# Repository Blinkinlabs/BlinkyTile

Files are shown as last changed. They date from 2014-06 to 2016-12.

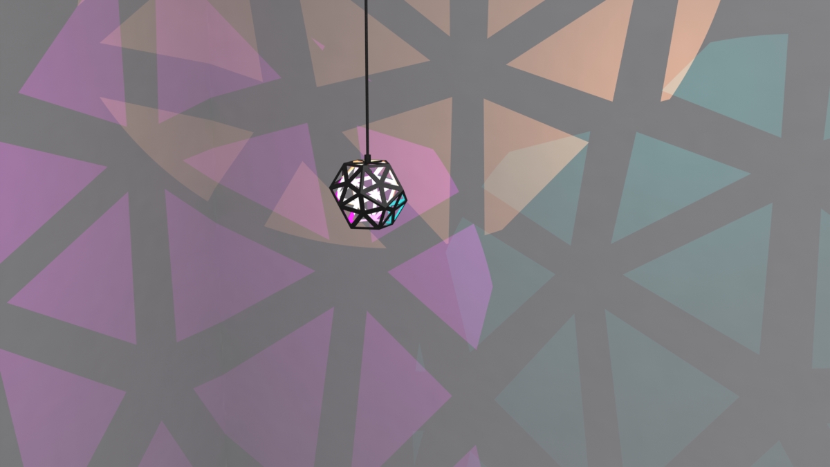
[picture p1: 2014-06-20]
concept_renderings/lamp concept.JPG

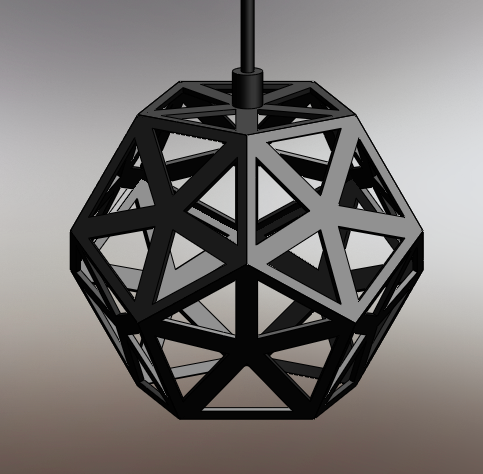
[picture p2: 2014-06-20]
concept_renderings/lamp base.jpg

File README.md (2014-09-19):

BlinkyTile: Build Your Own Dynamic Light Sculptures
==========



BlinkyTile is a very special type of pentagonal tile, designed to let you create your own custom light sculptures.

This is the source repository for the BlinkyTile design and software. For more information, head to:

http://blinkytile.com/

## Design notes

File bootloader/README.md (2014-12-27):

Modified Fadecandy Bootloader
=====

This is a simple open source bootloader for the Freescale Kinetis MK20DX128 microcontroller. It uses the USB Device Firmware Upgrade (DFU) standard. This bootloader was developed for use with Fadecandy, but it should be portable with to other projects using chips in the Kinetis microcontroller family, including the MK20DN64.

Installing
---

On a Teensy 3.0, you can use the Teensy Loader application to install `fc-boot.hex`. Afterwards, your Teensy should appear to the system as a "Fadecandy Bootloader" USB device capable of loading an application firmware image.

On a Fadecandy fc64x8 board, the bootloader can be installed via JTAG using OpenOCD. If you have an Olimex ARM-USB-OCD adapter, everything's already set up to install the bootloader with "make install". Other JTAG adapters will require changing `openocd.cfg`. Note: This may need to be modified to work with the LightBuddy microcontroller, specifically any sections referring to FlexRam.

Application Interface
---

This section describes the programming interface that exists between the bootloader and the application firmware.

The bootloader uses the smallest possible protected region on the MK20DX128's flash, a 4KB block. It uses a tiny amount of RAM for a "token" which is used to force entry into the bootloader on system reset.

When entering the application firmware, the system clocks will already be configured, and the watchdog timer is already enabled with a 10ms timeout. The application may disable the watchdog timer if desired.

The bootloader normally transfers control to the application early in boot, before setting up the USB controller. It will skip this step and run the DFU implementation if any of the following conditions are true:

* Both user buttons are pressed during power on (Manual recovery)
* A 32-bit entry token (0x74624346, or 'FCbt') is found at 0x2000_1FFC. (Programmatic entry)
* The application ResetVector does not reside within application flash. (No application is installed)

Memory address range       | Description
-------------------------- | ----------------------------
0x0000_0000 - 0x0000_0FFF  | Bootloader protected flash
0x0000_1000 - 0x0000_10F7  | Application IVT in flash
0x0000_1000 - 0x0001_FFFF  | Remainder of application flash
0x1FFF_E000 - 0x2000_1FFC  | Application SRAM
0x2000_1FFC - 0x2000_1FFF  | Entry token in SRAM

External Hardware
---

No external hardware is required for the bootloader to operate. The following pins are used by the bootloader for optional features:

* PD6 is a status LED, active (low) while the bootloader is in DFU mode.

File Format
---

The DFU file consists of raw 1 kilobyte blocks to be programmed into flash starting at address 0x0000_1000. The file may contain up to 63 blocks. No additional headers or checksums are included. On disk, the standard DFU suffix and CRC are used. During transit, the standard USB CRC is used.

Contact
---

Matt Mets <<matt@blinkinlabs.com>>

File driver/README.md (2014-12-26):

= Build a DFU driver for the BlinkyTile bootloader

Start with instructions here:
https://github.com/libusbx/libusbx/wiki/Windows-Backend#Driver_Installation

use this set for reference:
http://libusb-winusb-wip.googlecode.com/files/winusb%20driver.zip

Modify the 'libusb_device_multiple_interfaces_0' example to include the Light Buddy runtime interface.
Modify the 'libusb_device' example to include the Light Buddy interface

= Updating firmware on Windows

Get dfu-util 0.8 from the web site:
http://dfu-util.sourceforge.net/releases/dfu-util-0.8-binaries/win32-mingw32/

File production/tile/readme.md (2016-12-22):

The tile test jig is designed to run on a Teensy 3.0 or 3.1

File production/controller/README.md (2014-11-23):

Fadecandy Test Jig
==================

This is a simple one-off test fixture that's designed to facilitate in-circuit debugging of the Fadecandy firmware, and doing reliable low-volume production.

My prototype consists of:

* An ugly hand-wired perfboard
* 0.1"-spaced pogo pins which connect to the Fadecandy board's "hacker port" as well as its output header
* A standard ARM JTAG header for firmware development using an external JTAG adapter
* A 2-LED string of WS2811 LEDs, for verifying the timing of the Fadecandy outputs
* A Teensy 3.0 board which coordinates production and testing tasks

The board is intended for two separate use cases:

* During firmware development, it's a simple breakout board for the JTAG port
* During low-volume production, the Teensy installs firmware and performs electrical testing

This board is a work-in-progress. This directory contains Teensyduino sketches which run on the onboard Teensy. More information about the hardware will be included later.

Hardware tidbits
----------------

* JTAG port uses 10K pull-up resistors to target's' 3.3v rail on all signals.
* Pogo pins are 2x Digi-Key part ED8178-16-ND
* Big green button next to pogo-pins to initiate programming/test

Teensy 3.0 pin assignment
-------------------------

Pin      | Description
-------- | ----------------------------------
Gnd      | Shared ground
Vin      | +5V power for testjig itself
0        | Teensy RX, target TX
1        | Teensy TX, target RX
2        | To ground via green button
3        | target TCLK (SWCLK)
4        | target TMS (SWDIO)
5        | target USB D- (white wire)
6        | target USB D+ (green wire)
7        | target USB shield ground
8        | target USB signal ground
9        | (No connection)
10       | PWM out for power supply control
11       | PASS LED (to ground)
12       | FAIL LED (to ground)
13       | (Teensy built-in LED)
14 (A0)  | target output 0 (via resistor divider) PA4
15 (A1)  | target output 1 (via resistor divider) PB0
16 (A2)  | target output 2 (via resistor divider) PC1
17 (A3)  | target output 3 (via resistor divider)
18 (A4)  | target output 4 (via resistor divider)
19 (A5)  | target output 5 (via resistor divider)
20 (A6)  | target output 6 (via resistor divider) PB1
21 (A7)  | target output 7 (via resistor divider)
22 (A8)  | target 3.3v     (via resistor divider)
23 (A9)  | target VUSB     (via resistor divider)

All analog inputs connect via the same resistor divider:

* 1K between analog input and ground
* 6.8K between analog input and Fadecandy signal
* Use 5% tolerance resistors or better

Target power supply (micro-USB cable) is driven at a variable voltage. This is achieved by buffering a PWM output with an RC filter and op-amp.

* Op-amp should be able to drive ~20mA. I used half an OPA2350, since it was handy.
* Op-amp supply voltage driven by Teensy VUSB (~5V), bypassed with 0.1uF cap
* Configured as a non-inverting amplifier with gain=2
  * Feedback resistor, - to out, 68K
  * Feedback resistor, - to ground, 68K
* Low-pass filter on + input
  * 68K between + and PWM input
  * 0.1uF capacitor between + and ground
* Unused op-amps configured as followers
  * 33K from - to out
  * 33K from + to ground

The Teensy isn't capable of communicating over USB with the Fadecandy board when wired this way, but the USB pins are electrically tested in a minimal way. Note that the USB signal ground and shield ground are set up this way only for electrical testing. During testing and programming, the actual power and signal ground is achieved through the test clip's connection to the output port. Except for VUSB, all signals on the USB connector are used only to electrically test the USB connector itself.

Testjig Firmwares
-----------------

* `production`
	* Programs bootloader and initial firmware image
	* Runs electrical tests
	* Communicates with the DUT processor using Serial Wire Debug
* `serial_passthrough`
	* Teensyduino sketch
    * Appears as a USB serial port device
	* Passes through access to the DUT serial port
	* When the green button is held, acts as a loopback for the DUT serial port, as one way to enter FC-Boot.

Contact
-------

Micah Elizabeth Scott <<micah@scanlime.org>>

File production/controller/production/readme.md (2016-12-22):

Note:

For debug messages to work correctly, the Teensyduino build file needs to be modified. In:

	/c/Program Files (x86)/Arduino/hardware/teensy/avr/boards.txt

Change the line:

	teensy30.build.flags.ld=-Wl,--gc-sections,--relax,--defsym=__rtc_localtime={extra.time.local} "-T{build.core.path}/mk20dx128.ld"

to:

	teensy30.build.flags.ld=-Wl,-u_printf_float,--gc-sections,--relax,--defsym=__rtc_localtime={extra.time.local} "-T{build.core.path}/mk20dx128.ld"

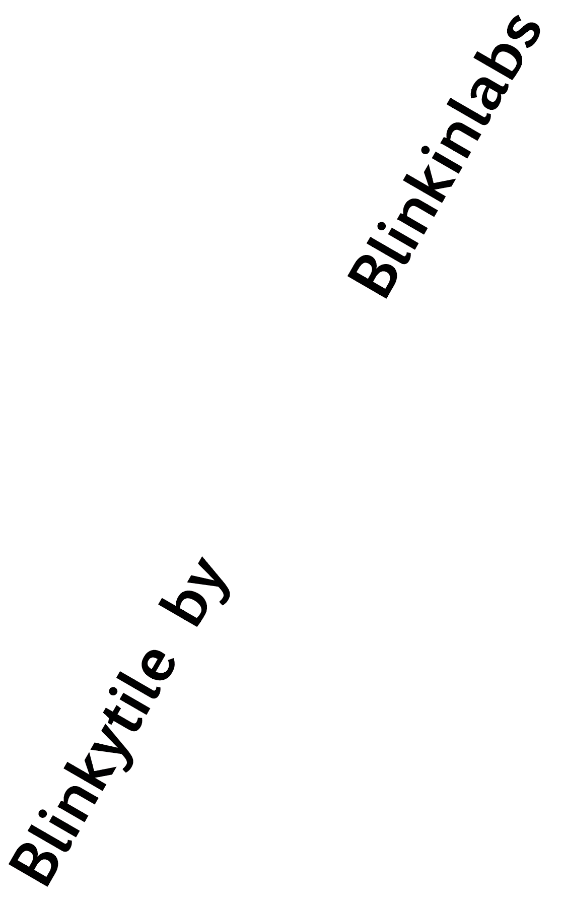
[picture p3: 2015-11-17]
tile_pcb/BlinkyTile Hexagon art.bmp

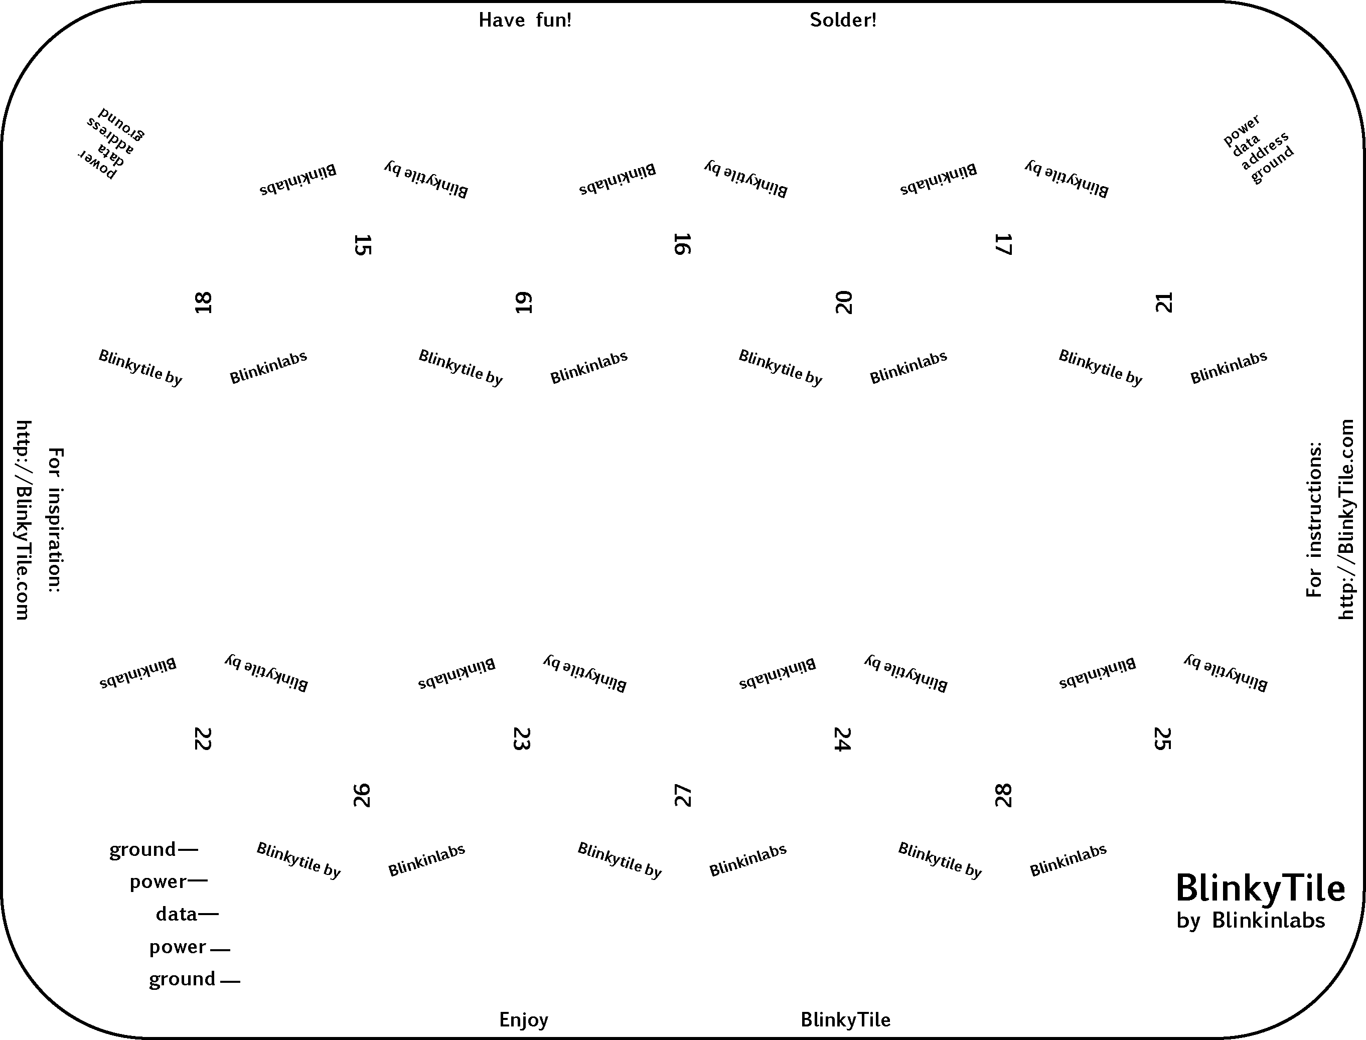
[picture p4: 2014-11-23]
tile_pcb/BlinkyTile_panel_15_28.BMP

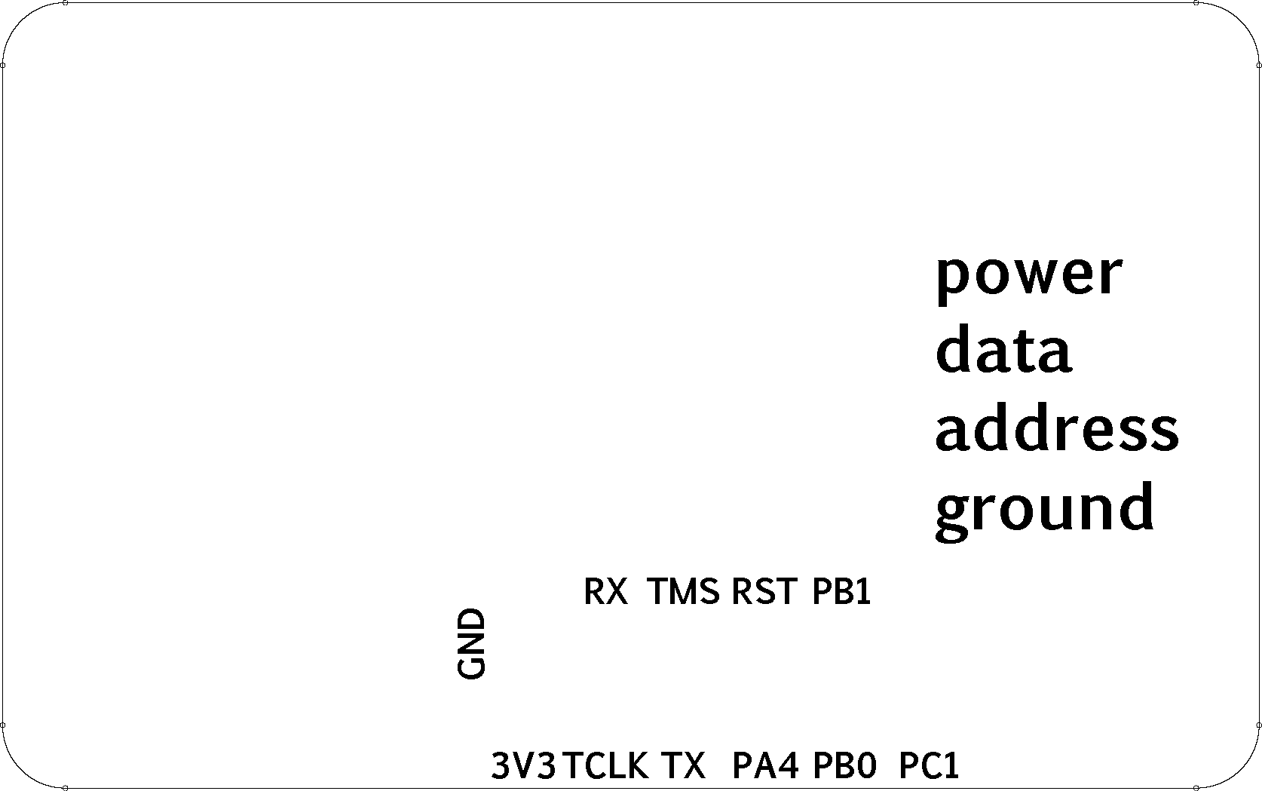
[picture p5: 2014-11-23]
controller_pcb/BlinkyTile Controller_Top.BMP

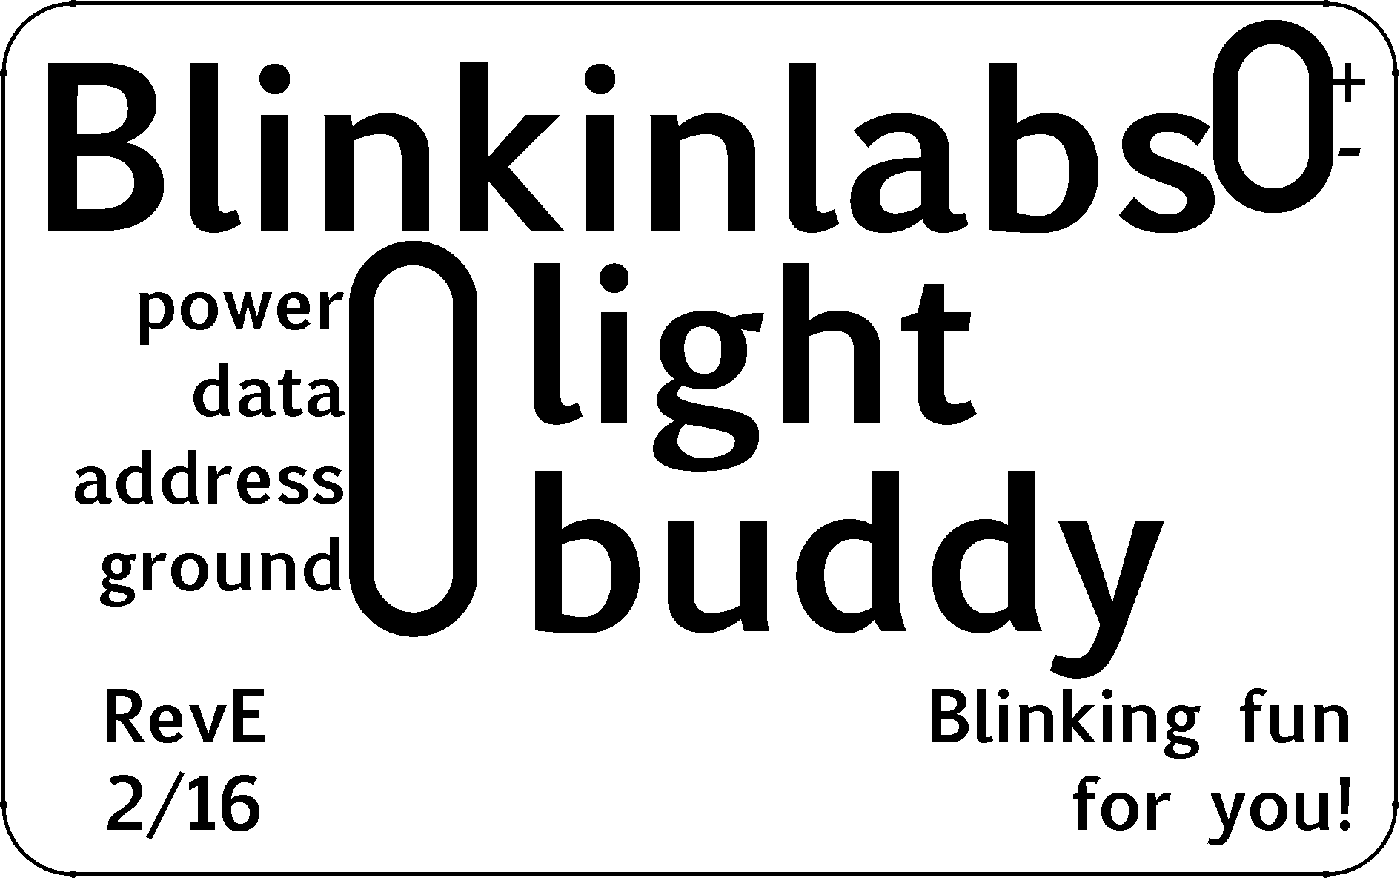
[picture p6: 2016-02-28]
controller_pcb/BlinkyTile Controller_Bottom.BMP

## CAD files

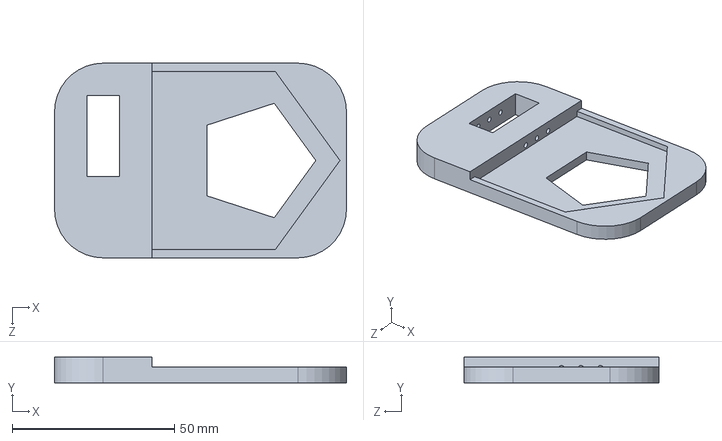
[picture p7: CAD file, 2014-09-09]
tile_programming_jig/programmer base.SLDPRT
90.0 x 8.00 x 60.0 mm

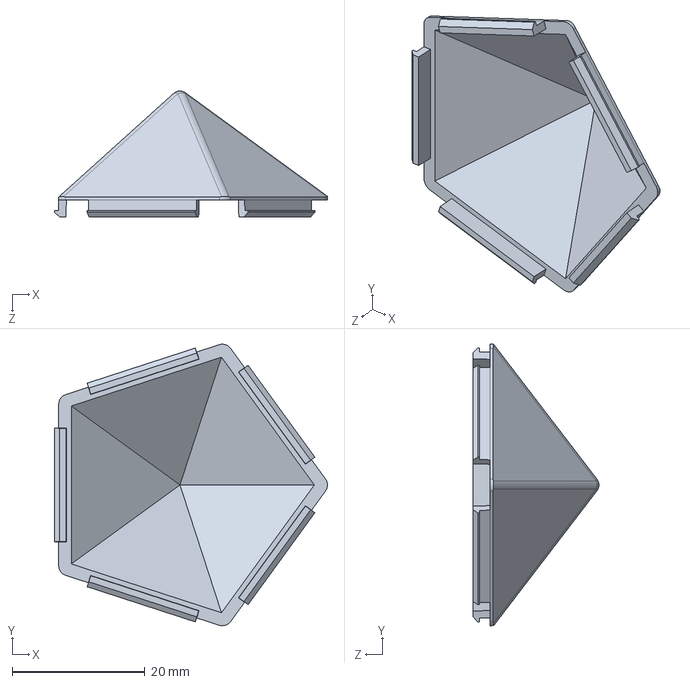
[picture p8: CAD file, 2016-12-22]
toppers/pyramid_nostep-revB-1.6mm-1.2clip.SLDPRT
41.2 x 42.5 x 19.0 mm

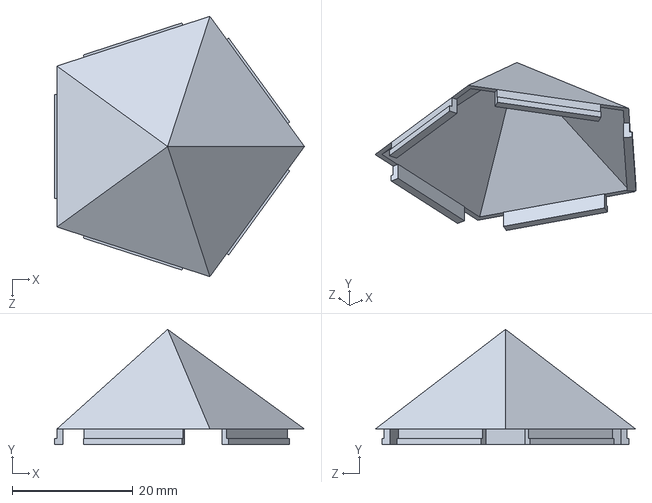
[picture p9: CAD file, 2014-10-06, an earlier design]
toppers/pyramid_nostep.SLDPRT
41.4 x 19.1 x 43.1 mm

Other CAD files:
toppers/pyramid_nostep-revB-1.5mm.STL
toppers/pyramid_nostep-revB.SLDPRT
tile_programming_jig/programmer base.STL
toppers/pyramid_nostep-revB-1.6mm-1.2clip.STL
toppers/pyramid_nostep-revB.STL
toppers/pyramid_nostep.STL

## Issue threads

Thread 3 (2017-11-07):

Blinky Tile firmware on Fade Candy

dunk8888, 2017-11-07:
Hi i was wondering if i could load blinky tile firmware on my fadecandy and use it with pattern paint?

dunk8888, 2017-11-07:
Also does the blinky tile run ws2812b leds too?

cibomahto, 2017-11-08:
Unfortunately, it's not compatible with the FadeCandy board- it's using a different processor and circuit. You'd need to re-write the firmware and add a flash chip to the FadeCandy board to make it work.

The supported firmware only supports BlinkyTile-style LEDs (DMX signalling with TTL line levels). There's an unsupported 'polyglot' branch that can output WS2812 control signals, but it is unstable.

The 'controller_pcb_tiny/' branch was a prototype of a smaller controller, but is also unfortunately not supported. If you're new to microcontroller development, I'd recommend using a different platform since this one is pretty hacky. In particular, I'd recommend looking at the ESP8266, and take a look at our EightByEight badge- we have support for that in PatternPaint, and the code could fairly easily be modified to output WS2812b outputs.

Closed 2017-11-08.

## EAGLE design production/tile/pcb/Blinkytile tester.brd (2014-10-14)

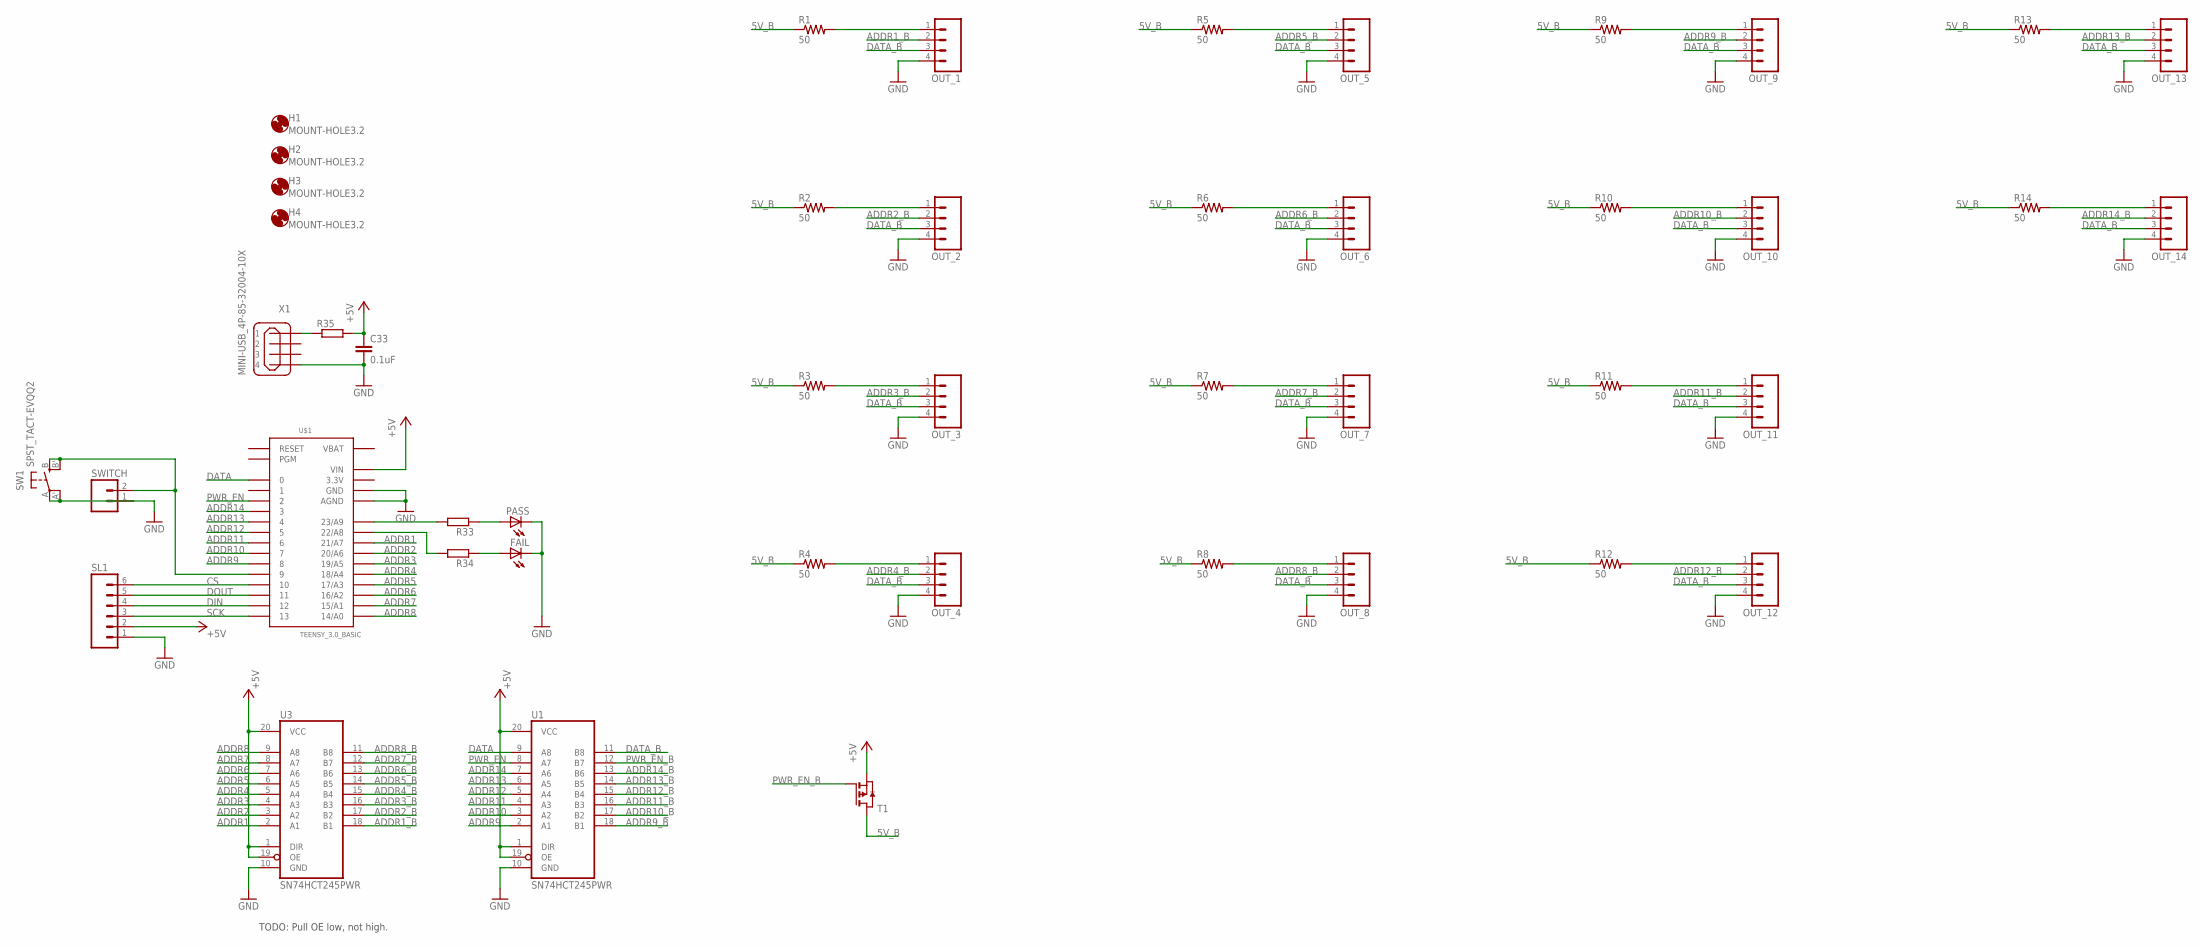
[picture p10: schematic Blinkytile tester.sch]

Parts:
C33: 0.1uF; C0805
FAIL: LED5MM
H1, H2, H3, H4: MOUNT-HOLE3.2; 3,2
OUT_1, OUT_2, OUT_3, OUT_4, OUT_5, OUT_6, OUT_7, OUT_8, OUT_9, OUT_10, OUT_11, OUT_12, OUT_13, OUT_14: M04; 04P
PASS: LED5MM
R1, R2, R3, R4, R5, R6, R7, R8, R9, R10, R11, R12, R13, R14: 50; R0603
R33, R34, R35: R-EU_M0805; M0805
SL1: M06; 06P
SW1: SPST_TACT-EVQQ2; EVQ-Q2
SWITCH: M02; 02P
T1: PMOSSOT223; SOT223
U1, U3: SN74HCT245PWR; TSSOP20
U$1: TEENSY_3.0_BASIC
X1: MINI-USB_4P-85-32004-10X; 85-32004-10X

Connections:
3.3V: U$1.3.3V, U$1.3.3V1 (3.3V)
5V_B: R1.1, R2.1, R3.1, R4.1, R5.1, R6.1, R7.1, R8.1, R9.1, R10.1, R11.1, R12.1, R13.1, R14.1, T1.2 (D), T1.4 (D)
+5V: C33.1, R35.2, SL1.2, T1.3 (S), U1.1 (DIR), U1.19 (OE), U1.20 (VCC), U3.1 (DIR), U3.19 (OE), U3.20 (VCC), U$1.VIN
ADDR1: U3.2 (A1), U$1.21/A7
ADDR1_B: OUT_1.2, U3.18 (B1)
ADDR2: U3.3 (A2), U$1.20/A6
ADDR2_B: OUT_2.2, U3.17 (B2)
ADDR3: U3.4 (A3), U$1.19/A5
ADDR3_B: OUT_3.2, U3.16 (B3)
ADDR4: U3.5 (A4), U$1.18/A4
ADDR4_B: OUT_4.2, U3.15 (B4)
ADDR5: U3.6 (A5), U$1.17/A3
ADDR5_B: OUT_5.2, U3.14 (B5)
ADDR6: U3.7 (A6), U$1.16/A2
ADDR6_B: OUT_6.2, U3.13 (B6)
ADDR7: U3.8 (A7), U$1.15/A1
ADDR7_B: OUT_7.2, U3.12 (B7)
ADDR8: U3.9 (A8), U$1.14/A0
ADDR8_B: OUT_8.2, U3.11 (B8)
ADDR9: U1.2 (A1), U$1.8
ADDR9_B: OUT_9.2, U1.18 (B1)
ADDR10: U1.3 (A2), U$1.7
ADDR10_B: OUT_10.2, U1.17 (B2)
ADDR11: U1.4 (A3), U$1.6
ADDR11_B: OUT_11.2, U1.16 (B3)
ADDR12: U1.5 (A4), U$1.5
ADDR12_B: OUT_12.2, U1.15 (B4)
ADDR13: U1.6 (A5), U$1.4
ADDR13_B: OUT_13.2, U1.14 (B5)
ADDR14: U1.7 (A6), U$1.3
ADDR14_B: OUT_14.2, U1.13 (B6)
CS: SL1.6, U$1.10
DATA: U1.9 (A8), U$1.0
DATA_B: OUT_1.3, OUT_2.3, OUT_3.3, OUT_4.3, OUT_5.3, OUT_6.3, OUT_7.3, OUT_8.3, OUT_9.3, OUT_10.3, OUT_11.3, OUT_12.3, OUT_13.3, OUT_14.3, U1.11 (B8)
DIN: SL1.4, U$1.12
DOUT: SL1.5, U$1.11
GND: C33.2, FAIL.K (C), OUT_1.4, OUT_2.4, OUT_3.4, OUT_4.4, OUT_5.4, OUT_6.4, OUT_7.4, OUT_8.4, OUT_9.4, OUT_10.4, OUT_11.4, OUT_12.4, OUT_13.4, OUT_14.4, PASS.K (C), SL1.1, SW1.A, SW1.A' (P1), SWITCH.1, U1.10 (GND), U3.10 (GND), U$1.AGND, U$1.GND, U$1.GND1 (GND), X1.4
GOOD: PASS.A, R33.1
unnamed: OUT_5.1, R5.2
unnamed: OUT_1.1, R1.2
unnamed: SW1.B (S), SW1.B' (S1), SWITCH.2, U$1.9
unnamed: OUT_2.1, R2.2
unnamed: OUT_3.1, R3.2
unnamed: OUT_4.1, R4.2
unnamed: OUT_6.1, R6.2
unnamed: OUT_7.1, R7.2
unnamed: OUT_8.1, R8.2
unnamed: OUT_9.1, R9.2
unnamed: OUT_10.1, R10.2
unnamed: OUT_11.1, R11.2
unnamed: OUT_13.1, R13.2
unnamed: OUT_14.1, R14.2
unnamed: OUT_12.1, R12.2
unnamed: R33.2, U$1.23/A9
unnamed: R34.2, U$1.22/A8
unnamed: FAIL.A, R34.1
unnamed: R35.1, X1.1
PWR_EN: U1.8 (A7), U$1.2
PWR_EN_B: T1.1 (G), U1.12 (B7)
SCK: SL1.3, U$1.13
VBAT: U$1.VBAT

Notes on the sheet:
TODO: Pull OE low, not high.

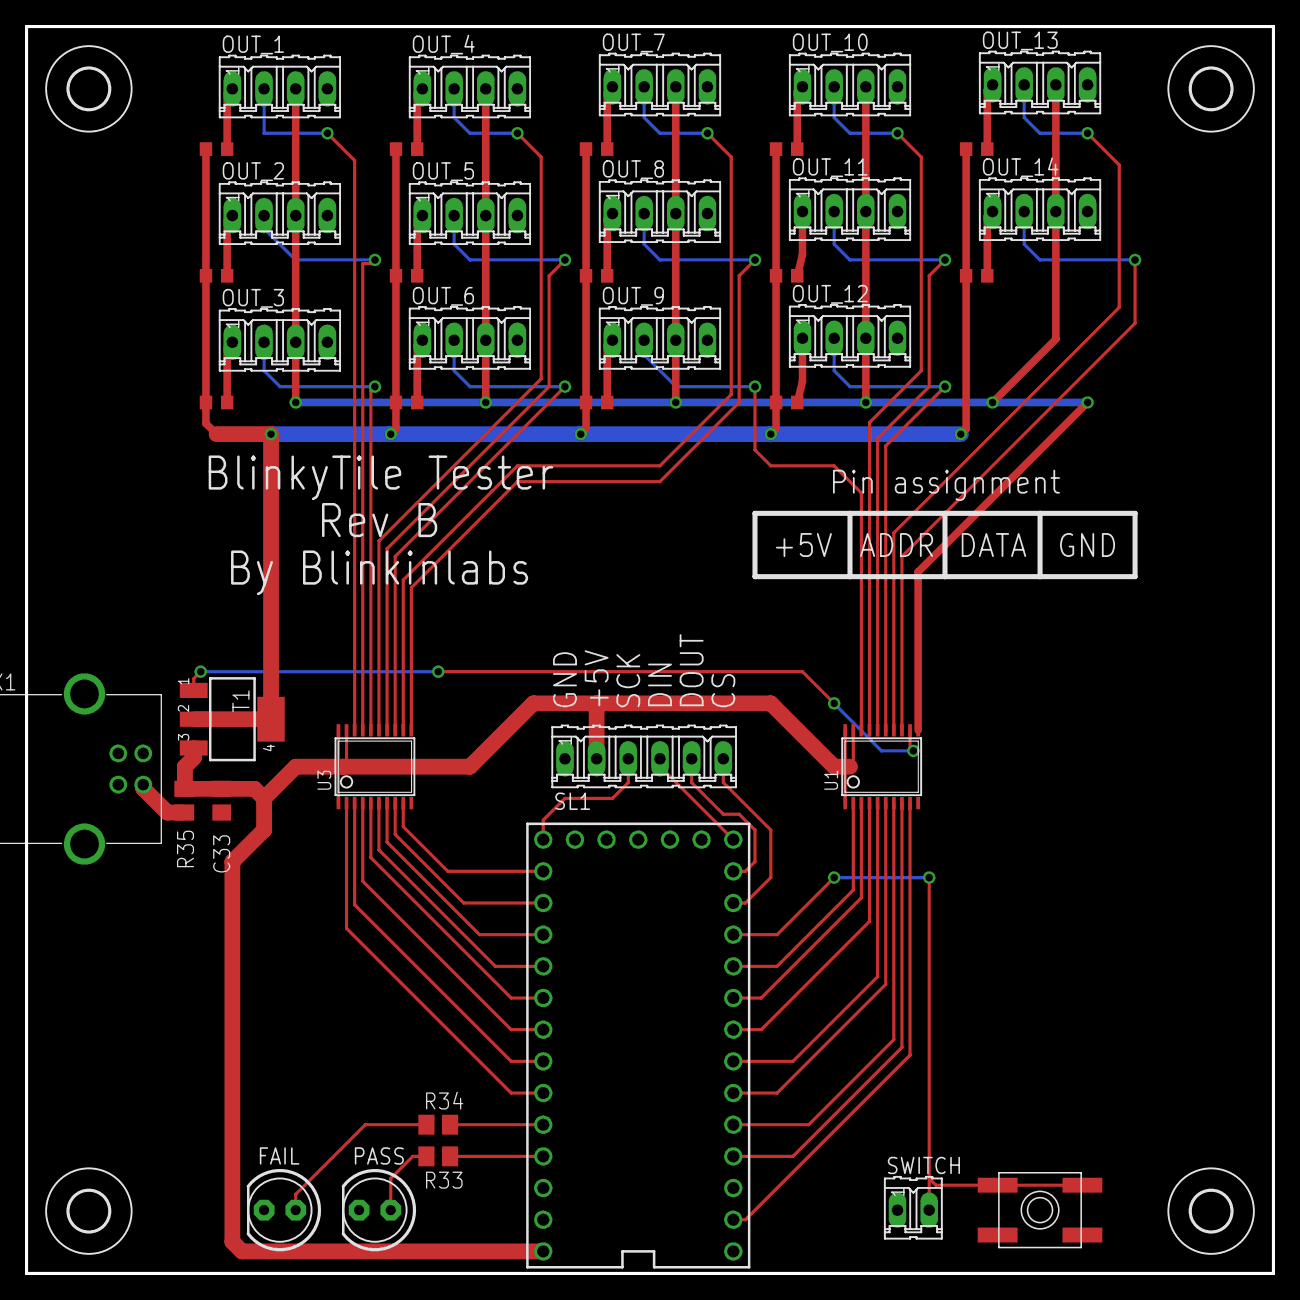
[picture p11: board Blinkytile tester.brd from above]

Board: 2 copper layers, 100.0 x 100.0 mm, 46 parts (0 on the bottom side), 60 nets.

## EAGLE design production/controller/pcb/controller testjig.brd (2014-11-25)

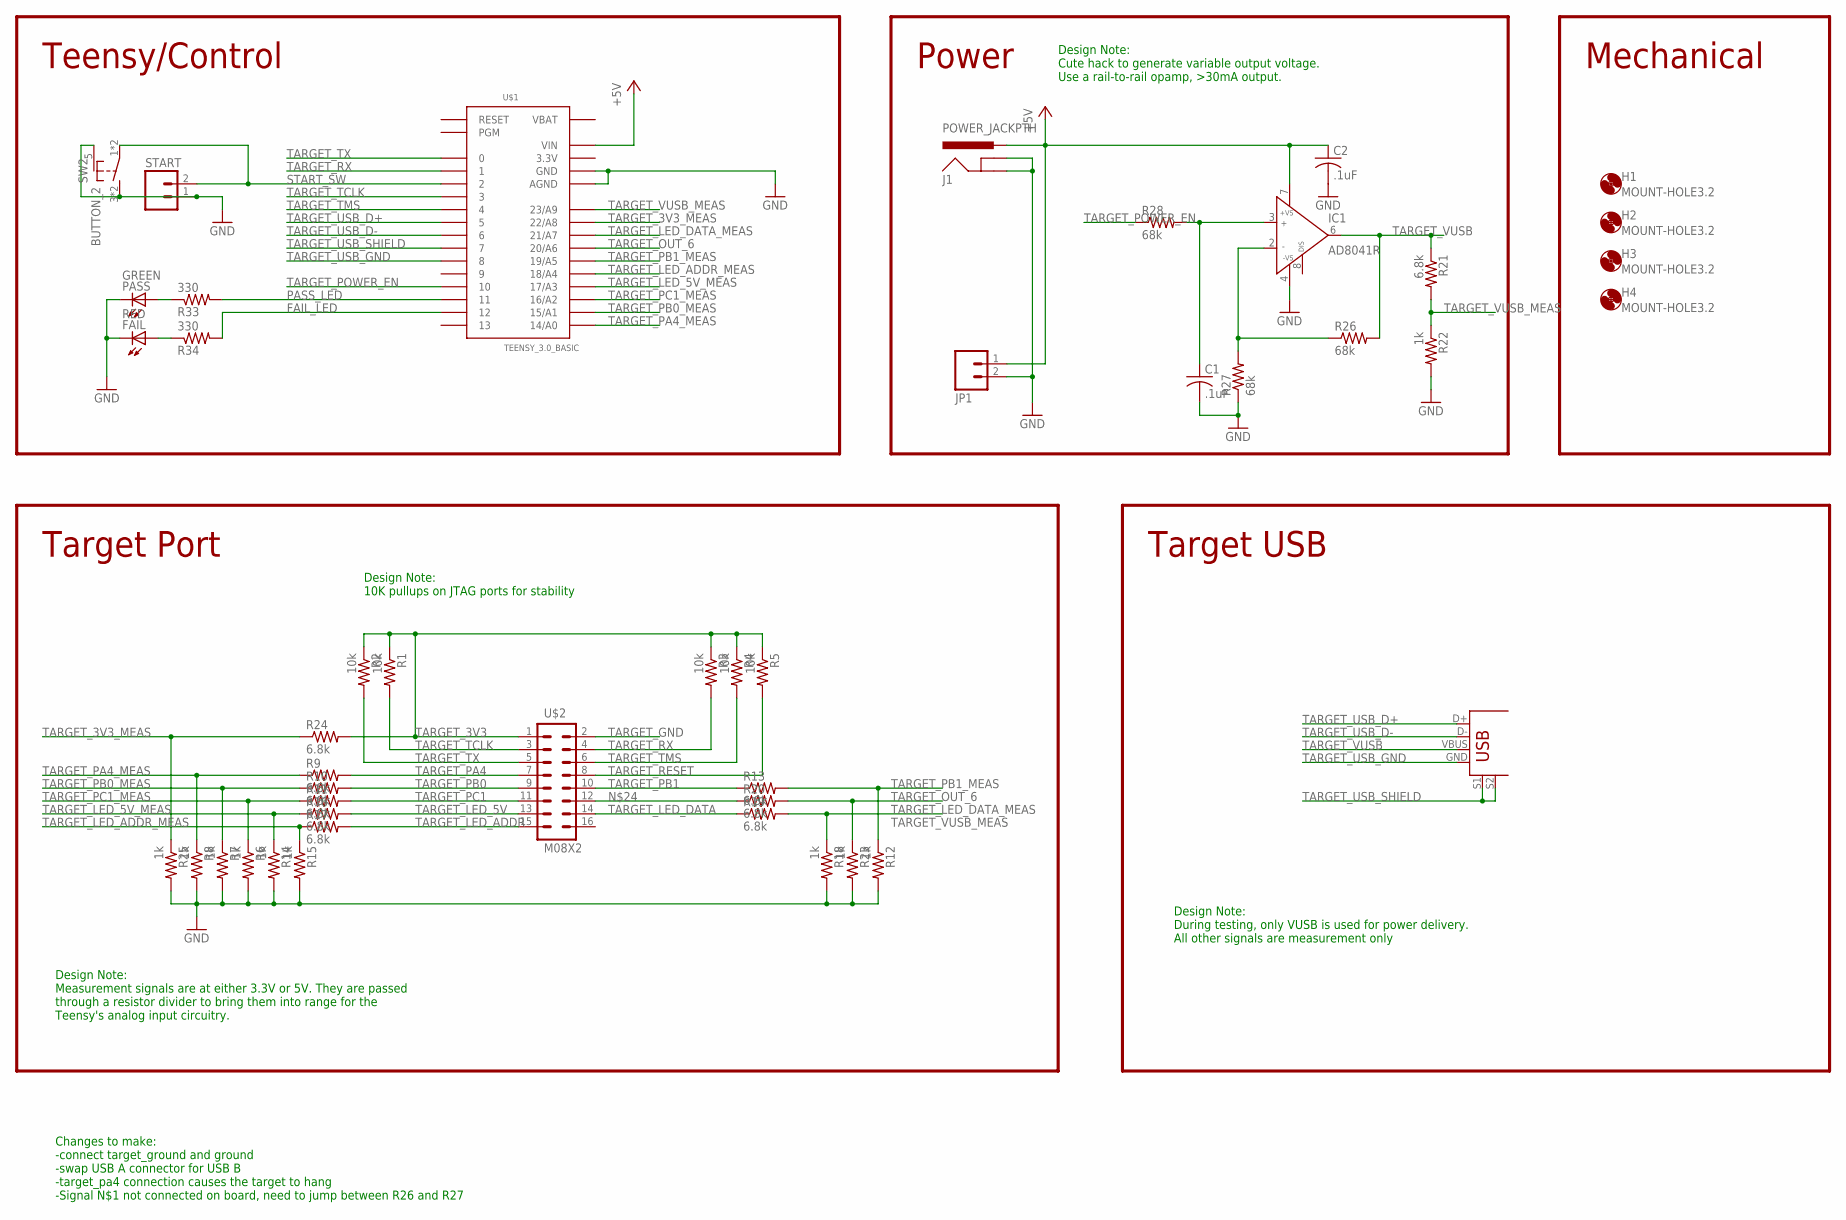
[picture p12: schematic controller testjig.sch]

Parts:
C1, C2: .1uF; C0603
FAIL: RED; LED5MM
H1, H2, H3, H4: MOUNT-HOLE3.2; 3,2
IC1: AD8041R; SO8
J1: POWER_JACKPTH; POWER_JACK_PTH
JP1: M023.5MM; SCREWTERMINAL-3.5MM-2
PASS: GREEN; LED5MM
R1, R2, R3, R4, R5: 10k; R0603
R6, R7, R8, R12, R14, R15, R18, R22, R23, R25: 1k; R0603
R9, R10, R11, R13, R16, R17, R19, R20, R21, R24: 6.8k; R0603
R26, R27, R28: 68k; R0603
R33, R34: 330; R0603
START: M02; 02P
SW2: BUTTON_2; TD-07XB
U$1: TEENSY_3.0_BASIC
U$2: M08X2; 2X8
U$3: USB+SHIELD; USB-B-PTH

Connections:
3.3V: U$1.3.3V, U$1.3.3V1 (3.3V)
+5V: C2.1, IC1.7 (+VS), J1.PWR, JP1.1, U$1.VIN
FAIL_LED: R34.2, U$1.12
GND: C1.2, C2.2, FAIL.K (C), IC1.4 (-VS), J1.GND, J1.GNDBREAK, JP1.2, PASS.K (C), R6.2, R7.2, R8.2, R12.2, R14.2, R15.2, R18.2, R22.2, R23.2, R25.2, R27.1, START.1, SW2.3 (S), SW2.4 (S), SW2.5 (SHIELD), U$1.AGND, U$1.GND, U$1.GND1 (GND)
GOOD: PASS.A, R33.1
unnamed: IC1.2 (IN-), R26.1, R27.2
unnamed: C1.1, IC1.3 (IN+), R28.2
unnamed: R20.1, U$2.12
unnamed: FAIL.A, R34.1
PASS_LED: R33.2, U$1.11
START_SW: START.2, SW2.1, SW2.2, U$1.2
TARGET_3V3: R1.1, R2.1, R3.1, R4.1, R5.1, R24.2, U$2.1
TARGET_3V3_MEAS: R24.1, R25.1, U$1.22/A8
TARGET_GND: U$2.2
TARGET_LED_5V: R16.2, U$2.13
TARGET_LED_5V_MEAS: R14.1, R16.1, U$1.17/A3
TARGET_LED_ADDR: R17.2, U$2.15
TARGET_LED_ADDR_MEAS: R15.1, R17.1, U$1.18/A4
TARGET_LED_DATA: R19.1, U$2.14
TARGET_LED_DATA_MEAS: R18.1, R19.2, U$1.21/A7
TARGET_OUT_6: R20.2, R23.1, U$1.20/A6
TARGET_PA4: R9.2, U$2.7
TARGET_PA4_MEAS: R8.1, R9.1, U$1.14/A0
TARGET_PB0: R10.2, U$2.9
TARGET_PB0_MEAS: R7.1, R10.1, U$1.15/A1
TARGET_PB1: R13.1, U$2.10
TARGET_PB1_MEAS: R12.1, R13.2, U$1.19/A5
TARGET_PC1: R11.2, U$2.11
TARGET_PC1_MEAS: R6.1, R11.1, U$1.16/A2
TARGET_POWER_EN: R28.1, U$1.10
TARGET_RESET: R5.2, U$2.8
TARGET_RX: R3.2, U$1.1, U$2.4
TARGET_TCLK: R1.2, U$1.3, U$2.3
TARGET_TMS: R4.2, U$1.4, U$2.6
TARGET_TX: R2.2, U$1.0, U$2.5
TARGET_USB_D+: U$1.5, U$3.D+
TARGET_USB_D-: U$1.6, U$3.D-
TARGET_USB_GND: U$1.8, U$3.GND
TARGET_USB_SHIELD: U$1.7, U$3.S1, U$3.S2
TARGET_VUSB: IC1.6 (OUT), R21.1, R26.2, U$3.VBUS
TARGET_VUSB_MEAS: R21.2, R22.1, U$1.23/A9
VBAT: U$1.VBAT

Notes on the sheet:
Teensy/Control
Target Port
Design Note: Measurement signals are at either 3.3V or 5V. They are passed through a resistor divider to bring them into range for the Teensy's analog input circuitry.
Design Note: 10K pullups on JTAG ports for stability
Mechanical
Target USB
Power
Design Note: During testing, only VUSB is used for power delivery. All other signals are measurement only
Design Note: Cute hack to generate variable output voltage. Use a rail-to-rail opamp, >30mA output.
Changes to make: -connect target_ground and ground -swap USB A connector for USB B -target_pa4 connection causes the target to hang -Signal N$1 not connected on board, need to jump between R26 and R27

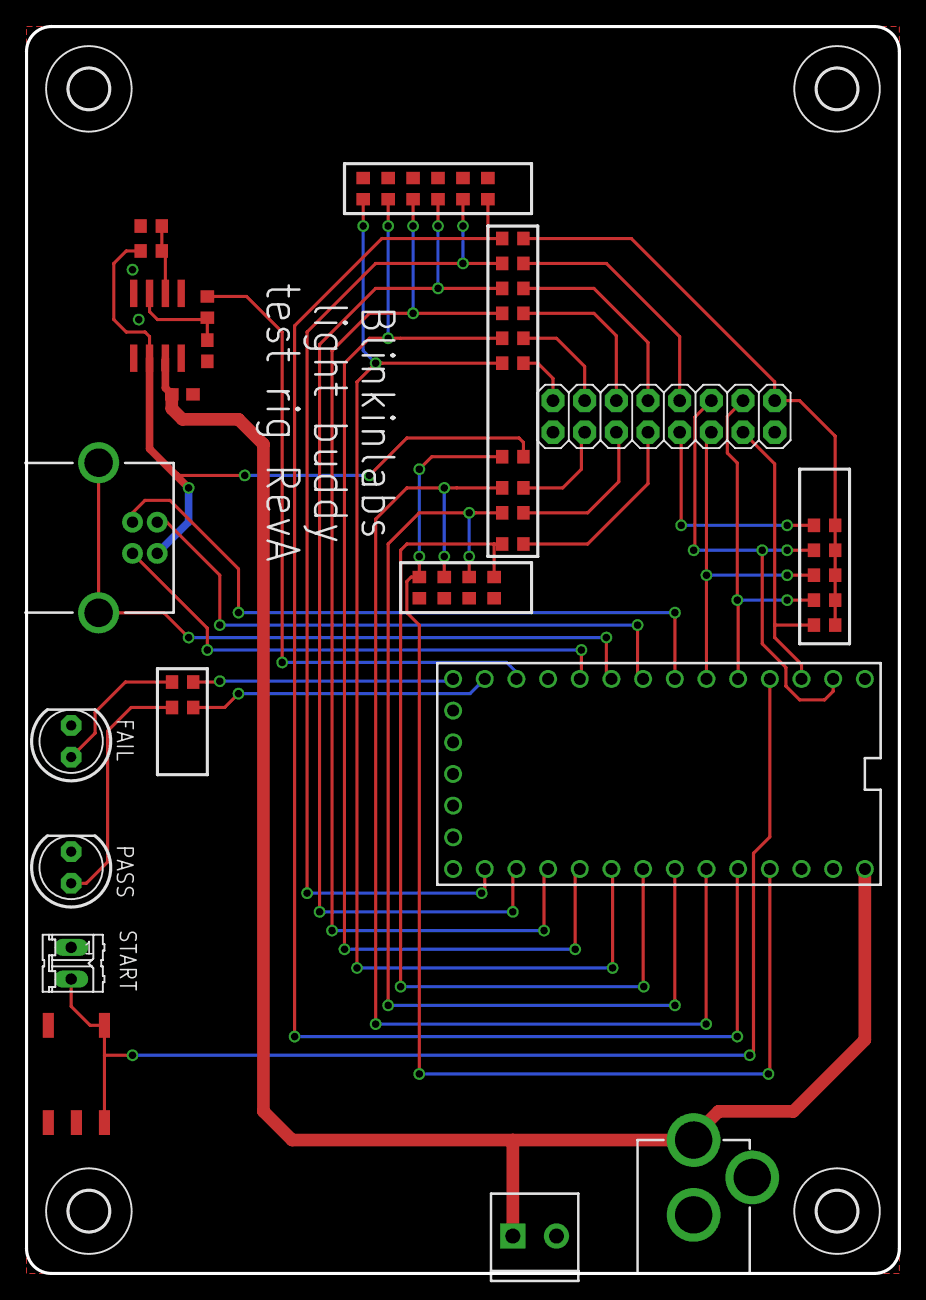
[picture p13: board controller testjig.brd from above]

Board: 2 copper layers, 70.0 x 100.0 mm, 46 parts (0 on the bottom side), 40 nets.

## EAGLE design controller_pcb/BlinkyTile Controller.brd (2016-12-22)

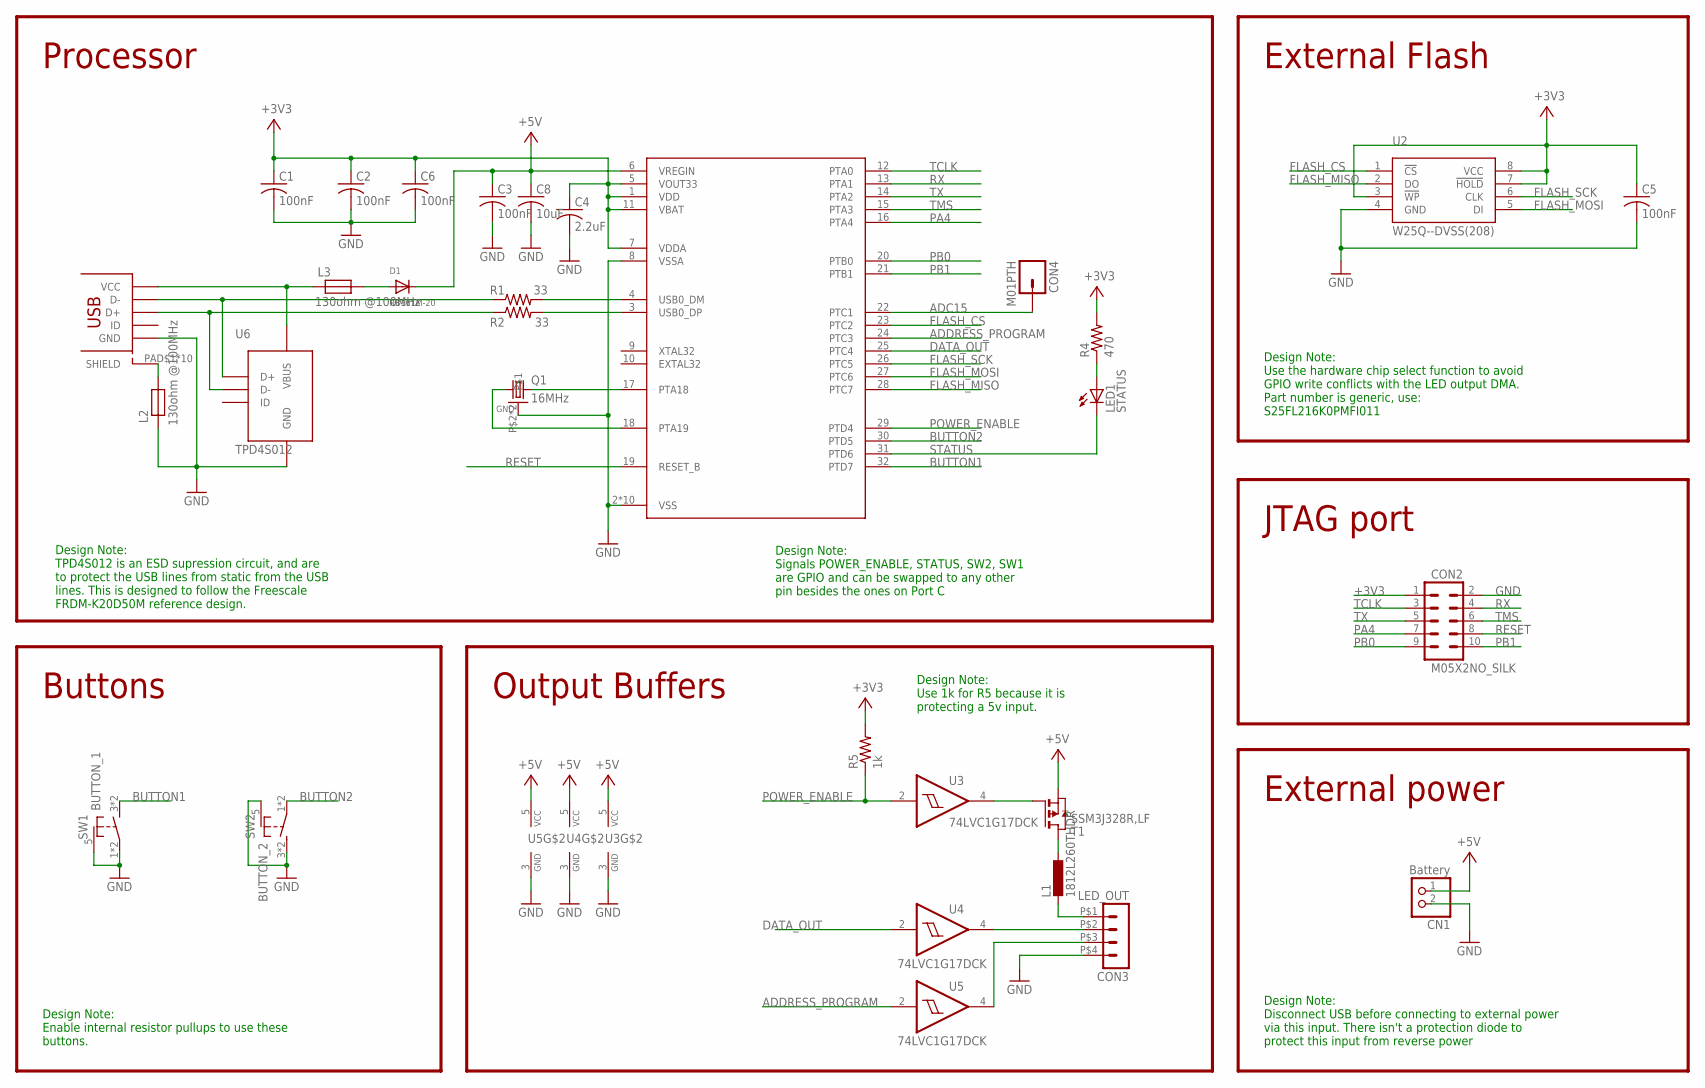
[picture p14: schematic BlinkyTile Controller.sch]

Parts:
C1, C2, C3, C5, C6: 100nF; C0402
C4: 2.2uF; C0402
C8: 10uF; C0805K
CN1: Battery; JST-PH-2-THM-RA
CON1: USB_MICROSMT+THRUHULE; USB_MICRO_THRUHOLE
CON2: M05X2NO_SILK; 2X5_NOSILK
CON3: LED_OUT; DUPONT-4P
CON4: M01PTH; 1X01
D1: RB161M-20; SOD-123
L1: 1812L260THDR; L1812
L2, L3: 130ohm @100MHz; 0805
LED1: STATUS; CHIPLED_0805
Q1: 16MHz; CRSYTAL_2520
R1, R2: 33; R0402
R4: 470; R0402
R5: 1k; R0402
SW1: BUTTON_1; TD-07XB
SW2: BUTTON_2; TD-07XB
T1: SSM3J328R,LF; SOT-23
U1: MK20D--VFM5; QFN32_5X5_LONGLEADS
U2: W25Q--DVSS(208); SOIC8-208
U3, U4, U5: 74LVC1G17DCK; SC70-5
U6: TPD4S012; R-PUSON-N6

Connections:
+3V3: C1.1, C2.1, C4.1, C5.1, C6.1, CON2.1, R4.2, R5.2, U1.1 (VDD), U1.5 (VOUT33), U1.7 (VDDA), U1.11 (VBAT), U2.3 (!WP), U2.7 (!HOLD), U2.8 (VCC)
+5V: C3.1, C8.1, CN1.1 (2), D1.C, T1.2 (S), U1.6 (VREGIN), U3.5 (VCC), U4.5 (VCC), U5.5 (VCC)
ADC15: CON4.1, U1.22 (PTC1)
ADDRESS_PROGRAM: U1.24 (PTC3), U5.2 (I)
BUTTON1: SW1.3 (S), SW1.4 (S), U1.32 (PTD7)
BUTTON2: SW2.1, SW2.2, U1.30 (PTD5)
DATA_OUT: U1.25 (PTC4), U4.2 (I)
FLASH_CS: U1.23 (PTC2), U2.1 (!CS)
FLASH_MISO: U1.28 (PTC7), U2.2 (DO)
FLASH_MOSI: U1.27 (PTC6), U2.5 (DI)
FLASH_SCK: U1.26 (PTC5), U2.6 (CLK)
GND: C1.2, C2.2, C3.2, C4.2, C5.2, C6.2, C8.2, CN1.2 (1), CON1.PIN$5 (GND), CON2.2, CON3.P$4 (4), L2.2, Q1.P$2, Q1.P$4, SW1.1, SW1.2, SW1.5 (SHIELD), SW2.3 (S), SW2.4 (S), SW2.5 (SHIELD), U1.2 (VSS), U1.8 (VSSA), U1.PAD@1 (VSS), U1.PAD@2 (VSS), U1.PAD@3 (VSS), U1.PAD@4 (VSS), U1.PAD@5 (VSS), U1.PAD@6 (VSS), U1.PAD@9 (VSS), U1.PAD@10 (VSS), U1.PAD@11 (VSS), U2.4 (GND), U3.3 (GND), U4.3 (GND), U5.3 (GND), U6.P$4 (GND)
LED_DATA: CON3.P$2 (2), U4.4 (O)
unnamed: Q1.P$1 (1), U1.18 (PTA19)
unnamed: Q1.P$3 (2), U1.17 (PTA18)
unnamed: CON1.PIN$1 (VCC), L3.2, U6.P$6 (VBUS)
unnamed: CON3.P$3 (3), U5.4 (O)
unnamed: L1.1, T1.1 (D)
unnamed: T1.3 (G), U3.4 (O)
unnamed: CON1.PIN$2 (D-), R1.1, U6.P$1 (D+)
unnamed: CON3.P$1 (1), L1.2
unnamed: D1.A, L3.1
unnamed: CON1.PIN$3 (D+), R2.1, U6.P$2 (D-)
unnamed: R1.2, U1.4 (USB0_DM)
unnamed: R2.2, U1.3 (USB0_DP)
unnamed: LED1.A, R4.1
PA4: CON2.7, U1.16 (PTA4)
PB0: CON2.9, U1.20 (PTB0)
PB1: CON2.10, U1.21 (PTB1)
POWER_ENABLE: R5.1, U1.29 (PTD4), U3.2 (I)
RESET: CON2.8, U1.19 (RESET_B)
RX: CON2.4, U1.13 (PTA1)
SHIELD: CON1.PAD$1 (SHIELD), CON1.PAD$2 (SHIELD), CON1.PAD$3 (SHIELD), CON1.PAD$4 (SHIELD), CON1.PAD$5 (SHIELD), CON1.PAD$6 (SHIELD), CON1.PAD$7 (SHIELD), CON1.PAD$8 (SHIELD), CON1.PAD$9 (SHIELD), CON1.PAD$10 (SHIELD), L2.1
STATUS: LED1.C, U1.31 (PTD6)
TCLK: CON2.3, U1.12 (PTA0)
TMS: CON2.6, U1.15 (PTA3)
TX: CON2.5, U1.14 (PTA2)

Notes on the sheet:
Processor
External Flash
Buttons
Design Note: Signals POWER_ENABLE, STATUS, SW2, SW1 are GPIO and can be swapped to any other pin besides the ones on Port C
Design Note: TPD4S012 is an ESD supression circuit, and are to protect the USB lines from static from the USB lines. This is designed to follow the Freescale FRDM-K20D50M reference design.
Output Buffers
JTAG port
External power
Design Note: Use 1k for R5 because it is protecting a 5v input.
Design Note: Use the hardware chip select function to avoid GPIO write conflicts with the LED output DMA. Part number is generic, use: S25FL216K0PMFI011
Design Note: Disconnect USB before connecting to external power via this input. There isn't a protection diode to protect this input from reverse power
Design Note: Enable internal resistor pullups to use these buttons.

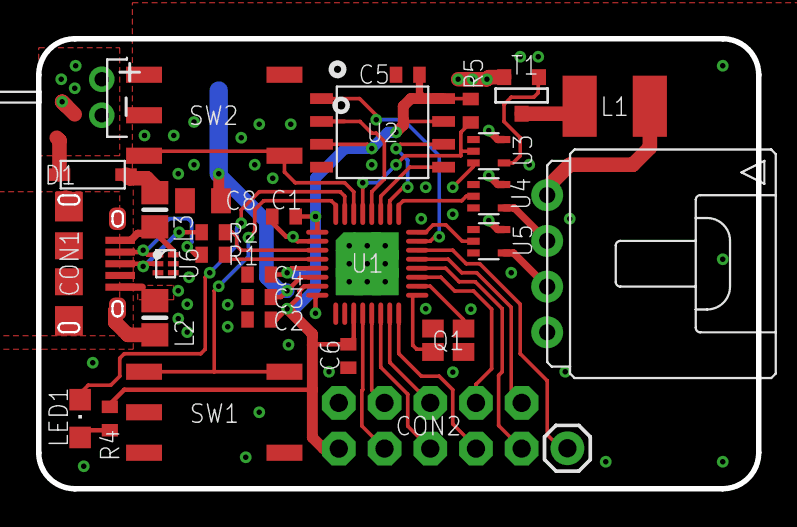
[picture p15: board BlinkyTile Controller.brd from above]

Board: 2 copper layers, 40.0 x 25.0 mm, 31 parts (0 on the bottom side), 37 nets.

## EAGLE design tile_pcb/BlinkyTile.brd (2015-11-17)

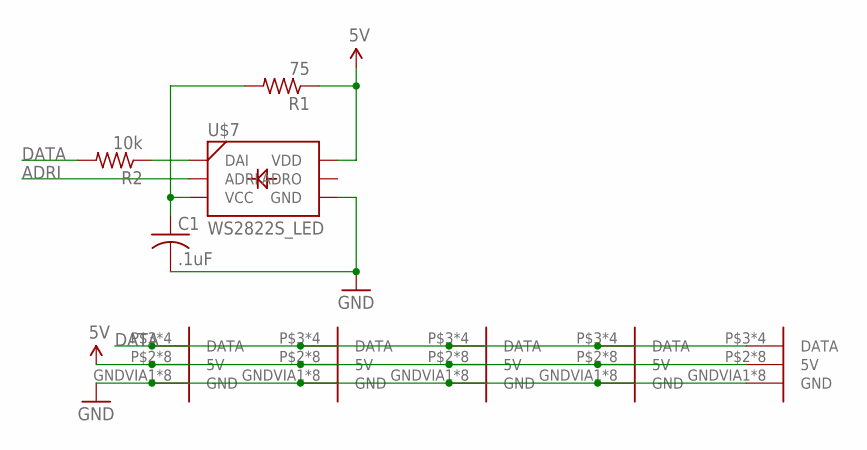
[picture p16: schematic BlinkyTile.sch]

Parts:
C1: .1uF; C0603
R1: 75; R0603
R2: 10k; R0603
U$2, U$3, U$4, U$5, U$6: D_EDGEMOD; D_EDGE_SLOT_MOD
U$7: WS2822S_LED

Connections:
5V: R1.1, U$2.P$2 (5V), U$2.P$4 (5V), U$2.P$7 (5V), U$2.P$9 (5V), U$2.PWRVIA1 (5V), U$2.PWRVIA3 (5V), U$2.PWRVIA4 (5V), U$2.PWRVIA6 (5V), U$3.P$2 (5V), U$3.P$4 (5V), U$3.P$7 (5V), U$3.P$9 (5V), U$3.PWRVIA1 (5V), U$3.PWRVIA3 (5V), U$3.PWRVIA4 (5V), U$3.PWRVIA6 (5V), U$4.P$2 (5V), U$4.P$4 (5V), U$4.P$7 (5V), U$4.P$9 (5V), U$4.PWRVIA1 (5V), U$4.PWRVIA3 (5V), U$4.PWRVIA4 (5V), U$4.PWRVIA6 (5V), U$5.P$2 (5V), U$5.P$4 (5V), U$5.P$7 (5V), U$5.P$9 (5V), U$5.PWRVIA1 (5V), U$5.PWRVIA3 (5V), U$5.PWRVIA4 (5V), U$5.PWRVIA6 (5V), U$6.P$2 (5V), U$6.P$4 (5V), U$6.P$7 (5V), U$6.P$9 (5V), U$6.PWRVIA1 (5V), U$6.PWRVIA3 (5V), U$6.PWRVIA4 (5V), U$6.PWRVIA6 (5V), U$7.6 (VDD)
ADRI: U$7.2 (ADRI)
DATA: R2.2, U$2.P$3 (DATA), U$2.P$8 (DATA), U$2.SIGVIA1 (DATA), U$2.SIGVIA3 (DATA), U$3.P$3 (DATA), U$3.P$8 (DATA), U$3.SIGVIA1 (DATA), U$3.SIGVIA3 (DATA), U$4.P$3 (DATA), U$4.P$8 (DATA), U$4.SIGVIA1 (DATA), U$4.SIGVIA3 (DATA), U$5.P$3 (DATA), U$5.P$8 (DATA), U$5.SIGVIA1 (DATA), U$5.SIGVIA3 (DATA), U$6.P$3 (DATA), U$6.P$8 (DATA), U$6.SIGVIA1 (DATA), U$6.SIGVIA3 (DATA)
GND: C1.2, U$2.GNDVIA1 (GND), U$2.GNDVIA3 (GND), U$2.GNDVIA4 (GND), U$2.GNDVIA6 (GND), U$2.P$1 (GND), U$2.P$5 (GND), U$2.P$6 (GND), U$2.P$10 (GND), U$3.GNDVIA1 (GND), U$3.GNDVIA3 (GND), U$3.GNDVIA4 (GND), U$3.GNDVIA6 (GND), U$3.P$1 (GND), U$3.P$5 (GND), U$3.P$6 (GND), U$3.P$10 (GND), U$4.GNDVIA1 (GND), U$4.GNDVIA3 (GND), U$4.GNDVIA4 (GND), U$4.GNDVIA6 (GND), U$4.P$1 (GND), U$4.P$5 (GND), U$4.P$6 (GND), U$4.P$10 (GND), U$5.GNDVIA1 (GND), U$5.GNDVIA3 (GND), U$5.GNDVIA4 (GND), U$5.GNDVIA6 (GND), U$5.P$1 (GND), U$5.P$5 (GND), U$5.P$6 (GND), U$5.P$10 (GND), U$6.GNDVIA1 (GND), U$6.GNDVIA3 (GND), U$6.GNDVIA4 (GND), U$6.GNDVIA6 (GND), U$6.P$1 (GND), U$6.P$5 (GND), U$6.P$6 (GND), U$6.P$10 (GND), U$7.4 (GND)
unnamed: C1.1, R1.2, U$7.3 (VCC)
unnamed: R2.1, U$7.1 (DAI)

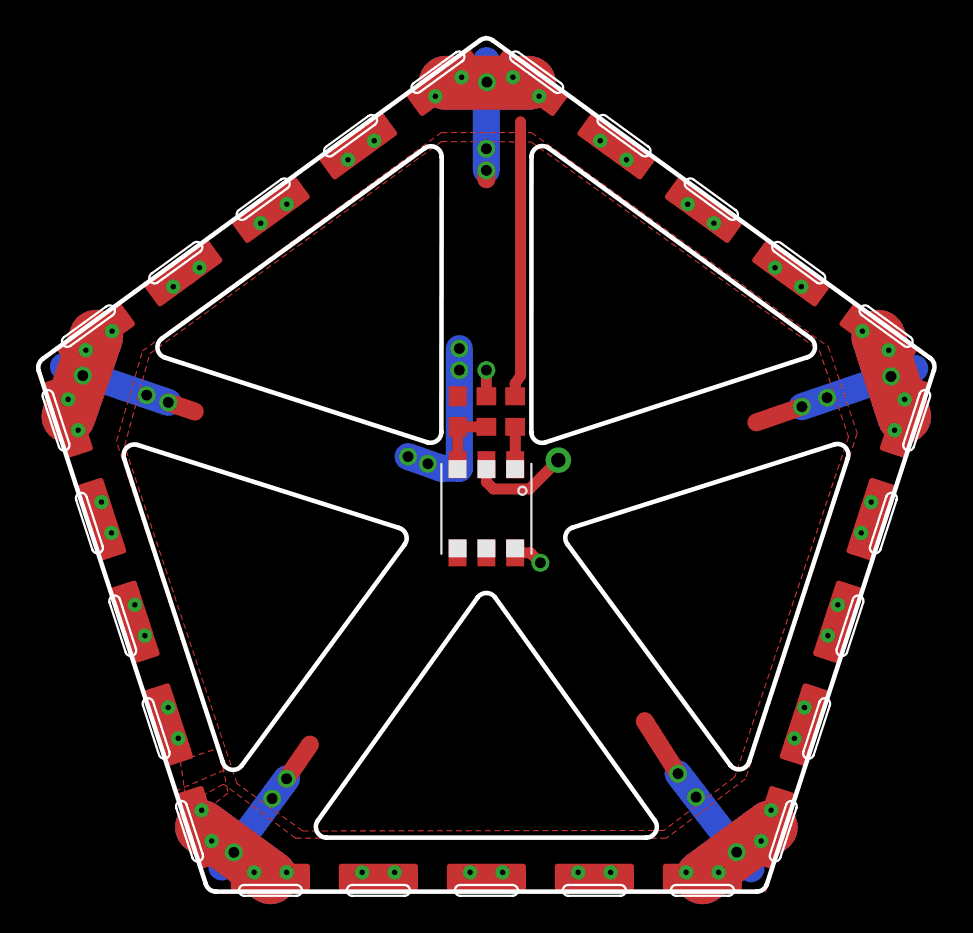
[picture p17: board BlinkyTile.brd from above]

Board: 2 copper layers, 49.8 x 47.4 mm, 9 parts (0 on the bottom side), 5 nets.

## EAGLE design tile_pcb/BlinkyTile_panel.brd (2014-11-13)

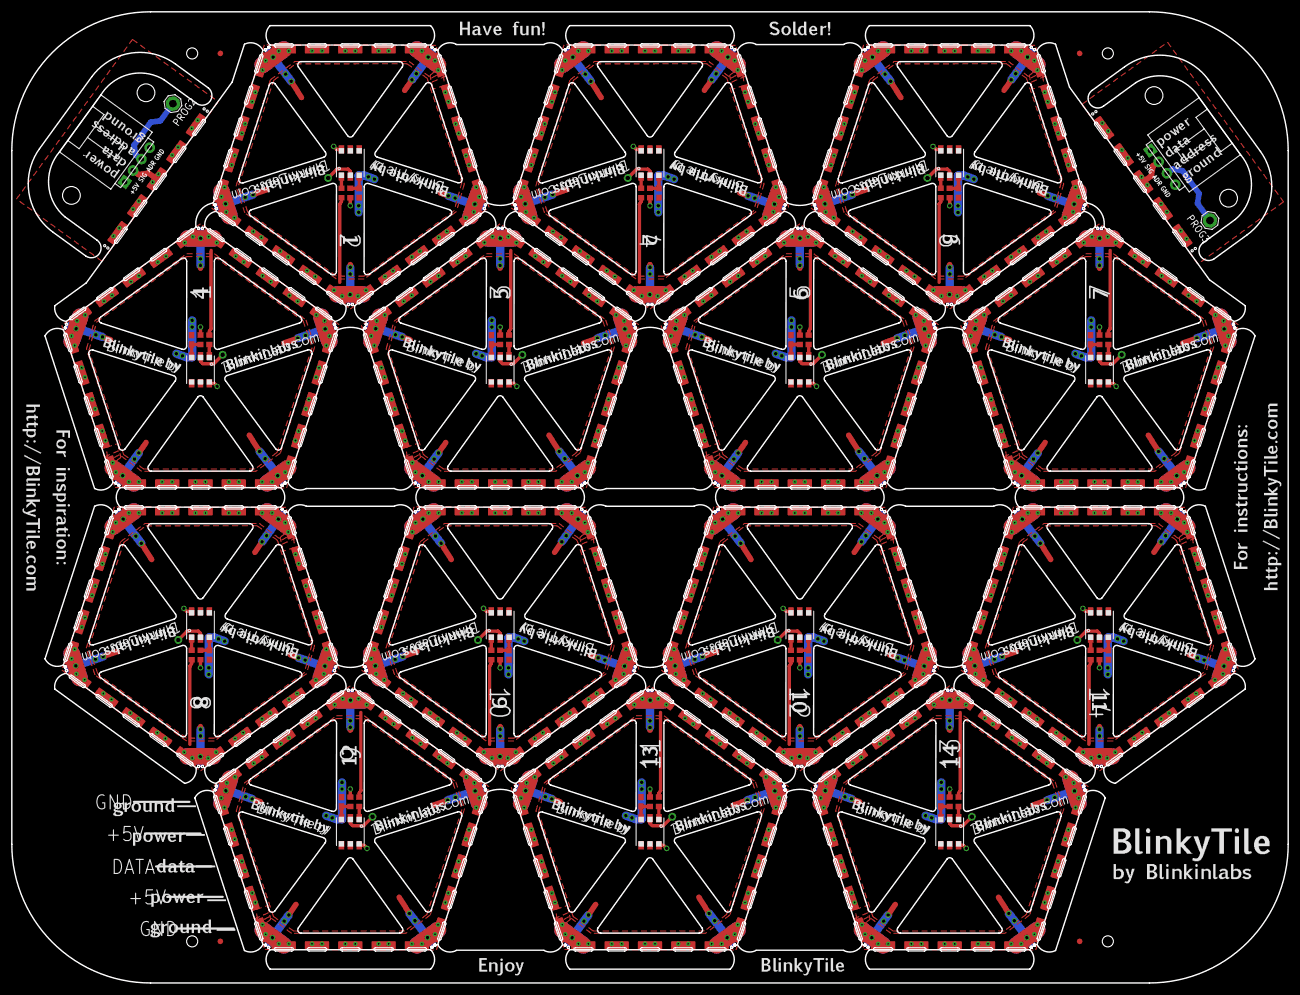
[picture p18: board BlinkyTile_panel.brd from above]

Board: 2 copper layers, 230.0 x 175.0 mm, 322 parts (0 on the bottom side), 78 nets.

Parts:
C2, C3, C4, C5, C6, C7, C8, C9, C10, C11, C12, C13, C14, C15: .1uF; C0603
E$1, E$2, E$221, E$224: FIDUCIAL-1X2
E$23, E$24, E$25, E$26, E$27, E$28, E$29, E$30, E$31, E$32, E$33, E$34, E$35, E$36, E$37, E$38, E$39, E$40, E$41, E$42, E$43, E$44, E$45, E$46, E$49, E$50, E$51, E$52, E$53, E$54, E$56, E$57, E$58, E$59, E$60, E$61, E$62, E$63, E$64, E$65, E$66, E$67, E$68, E$69, E$70, E$71, E$72, E$73, E$74, E$75, E$76, E$77, E$78, E$79, E$80, E$81, E$82, E$83, E$84, E$85, E$86, E$87, E$88, E$89, E$90, E$91, E$92, E$93, E$94, E$95, E$96, E$97, E$98, E$99, E$100, E$101, E$102, E$103, E$104, E$105, E$106, E$107, E$108, E$109, E$110, E$111, E$112, E$113, E$114, E$115, E$116, E$117, E$118, E$119, E$120, E$121, E$122, E$123, E$124, E$125, E$126, E$127, E$128, E$129, E$130, E$131, E$132, E$133, E$134, E$135, E$136, E$137, E$138, E$139, E$140, E$141, E$142, E$143, E$144, E$145, E$146, E$147, E$148, E$149, E$150, E$151, E$152, E$153, E$154, E$155, E$156, E$157, E$158, E$159, E$160, E$161, E$162, E$163, E$164, E$165, E$166, E$167, E$168, E$169, E$170, E$171, E$172, E$173, E$174, E$175, E$176, E$177, E$178, E$179, E$180, E$181, E$182, E$183, E$184, E$185, E$186, E$187, E$188, E$189, E$190, E$191, E$192, E$193, E$199, E$200, E$202, E$203: MOUSE_BITE_1
E$201, E$204: 4-PIN_DUPONT
E$205, E$206, E$207, E$208, E$209, E$210, E$211, E$212, E$213, E$214, E$215, E$216, E$217, E$218: BLINKYTILE
PROG2, PROG3: SE14
R3, R5, R7, R9, R11, R13, R15, R17, R19, R21, R23, R25, R27, R29: 75; R0603
R4, R6, R8, R10, R12, R14, R16, R18, R20, R22, R24, R26, R28, R30: 10k; R0603
U$1, U$8, U$9, U$10, U$11, U$13, U$14, U$15, U$16, U$17, U$19, U$20, U$21, U$22, U$23, U$25, U$26, U$27, U$28, U$29, U$31, U$32, U$33, U$34, U$35, U$37, U$38, U$39, U$40, U$41, U$43, U$44, U$45, U$46, U$47, U$49, U$50, U$51, U$52, U$53, U$55, U$56, U$57, U$58, U$59, U$61, U$62, U$63, U$64, U$65, U$67, U$68, U$69, U$70, U$71, U$73, U$74, U$75, U$76, U$77, U$79, U$80, U$81, U$82, U$83, U$85, U$86, U$87, U$88, U$89, U$93, U$94: D_EDGEMOD; D_EDGE_SLOT_MOD
U$12, U$18, U$24, U$30, U$36, U$42, U$48, U$54, U$60, U$66, U$72, U$78, U$84, U$90: WS2822S_LED

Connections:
5V2: R3.1, U$1.P$2, U$1.P$4, U$1.P$7, U$1.P$9, U$1.PWRVIA1, U$1.PWRVIA3, U$1.PWRVIA4, U$1.PWRVIA6, U$8.P$2, U$8.P$4, U$8.P$7, U$8.P$9, U$8.PWRVIA1, U$8.PWRVIA3, U$8.PWRVIA4, U$8.PWRVIA6, U$9.P$2, U$9.P$4, U$9.P$7, U$9.P$9, U$9.PWRVIA1, U$9.PWRVIA3, U$9.PWRVIA4, U$9.PWRVIA6, U$10.P$2, U$10.P$4, U$10.P$7, U$10.P$9, U$10.PWRVIA1, U$10.PWRVIA3, U$10.PWRVIA4, U$10.PWRVIA6, U$11.P$2, U$11.P$4, U$11.P$7, U$11.P$9, U$11.PWRVIA1, U$11.PWRVIA3, U$11.PWRVIA4, U$11.PWRVIA6, U$12.6
5V3: R5.1, U$13.P$2, U$13.P$4, U$13.P$7, U$13.P$9, U$13.PWRVIA1, U$13.PWRVIA3, U$13.PWRVIA4, U$13.PWRVIA6, U$14.P$2, U$14.P$4, U$14.P$7, U$14.P$9, U$14.PWRVIA1, U$14.PWRVIA3, U$14.PWRVIA4, U$14.PWRVIA6, U$15.P$2, U$15.P$4, U$15.P$7, U$15.P$9, U$15.PWRVIA1, U$15.PWRVIA3, U$15.PWRVIA4, U$15.PWRVIA6, U$16.P$2, U$16.P$4, U$16.P$7, U$16.P$9, U$16.PWRVIA1, U$16.PWRVIA3, U$16.PWRVIA4, U$16.PWRVIA6, U$17.P$2, U$17.P$4, U$17.P$7, U$17.P$9, U$17.PWRVIA1, U$17.PWRVIA3, U$17.PWRVIA4, U$17.PWRVIA6, U$18.6
5V4: R7.1, U$19.P$2, U$19.P$4, U$19.P$7, U$19.P$9, U$19.PWRVIA1, U$19.PWRVIA3, U$19.PWRVIA4, U$19.PWRVIA6, U$20.P$2, U$20.P$4, U$20.P$7, U$20.P$9, U$20.PWRVIA1, U$20.PWRVIA3, U$20.PWRVIA4, U$20.PWRVIA6, U$21.P$2, U$21.P$4, U$21.P$7, U$21.P$9, U$21.PWRVIA1, U$21.PWRVIA3, U$21.PWRVIA4, U$21.PWRVIA6, U$22.P$2, U$22.P$4, U$22.P$7, U$22.P$9, U$22.PWRVIA1, U$22.PWRVIA3, U$22.PWRVIA4, U$22.PWRVIA6, U$23.P$2, U$23.P$4, U$23.P$7, U$23.P$9, U$23.PWRVIA1, U$23.PWRVIA3, U$23.PWRVIA4, U$23.PWRVIA6, U$24.6
5V5: R9.1, U$25.P$2, U$25.P$4, U$25.P$7, U$25.P$9, U$25.PWRVIA1, U$25.PWRVIA3, U$25.PWRVIA4, U$25.PWRVIA6, U$26.P$2, U$26.P$4, U$26.P$7, U$26.P$9, U$26.PWRVIA1, U$26.PWRVIA3, U$26.PWRVIA4, U$26.PWRVIA6, U$27.P$2, U$27.P$4, U$27.P$7, U$27.P$9, U$27.PWRVIA1, U$27.PWRVIA3, U$27.PWRVIA4, U$27.PWRVIA6, U$28.P$2, U$28.P$4, U$28.P$7, U$28.P$9, U$28.PWRVIA1, U$28.PWRVIA3, U$28.PWRVIA4, U$28.PWRVIA6, U$29.P$2, U$29.P$4, U$29.P$7, U$29.P$9, U$29.PWRVIA1, U$29.PWRVIA3, U$29.PWRVIA4, U$29.PWRVIA6, U$30.6
5V6: R11.1, U$31.P$2, U$31.P$4, U$31.P$7, U$31.P$9, U$31.PWRVIA1, U$31.PWRVIA3, U$31.PWRVIA4, U$31.PWRVIA6, U$32.P$2, U$32.P$4, U$32.P$7, U$32.P$9, U$32.PWRVIA1, U$32.PWRVIA3, U$32.PWRVIA4, U$32.PWRVIA6, U$33.P$2, U$33.P$4, U$33.P$7, U$33.P$9, U$33.PWRVIA1, U$33.PWRVIA3, U$33.PWRVIA4, U$33.PWRVIA6, U$34.P$2, U$34.P$4, U$34.P$7, U$34.P$9, U$34.PWRVIA1, U$34.PWRVIA3, U$34.PWRVIA4, U$34.PWRVIA6, U$35.P$2, U$35.P$4, U$35.P$7, U$35.P$9, U$35.PWRVIA1, U$35.PWRVIA3, U$35.PWRVIA4, U$35.PWRVIA6, U$36.6
5V7: R13.1, U$37.P$2, U$37.P$4, U$37.P$7, U$37.P$9, U$37.PWRVIA1, U$37.PWRVIA3, U$37.PWRVIA4, U$37.PWRVIA6, U$38.P$2, U$38.P$4, U$38.P$7, U$38.P$9, U$38.PWRVIA1, U$38.PWRVIA3, U$38.PWRVIA4, U$38.PWRVIA6, U$39.P$2, U$39.P$4, U$39.P$7, U$39.P$9, U$39.PWRVIA1, U$39.PWRVIA3, U$39.PWRVIA4, U$39.PWRVIA6, U$40.P$2, U$40.P$4, U$40.P$7, U$40.P$9, U$40.PWRVIA1, U$40.PWRVIA3, U$40.PWRVIA4, U$40.PWRVIA6, U$41.P$2, U$41.P$4, U$41.P$7, U$41.P$9, U$41.PWRVIA1, U$41.PWRVIA3, U$41.PWRVIA4, U$41.PWRVIA6, U$42.6
5V8: R15.1, U$43.P$2, U$43.P$4, U$43.P$7, U$43.P$9, U$43.PWRVIA1, U$43.PWRVIA3, U$43.PWRVIA4, U$43.PWRVIA6, U$44.P$2, U$44.P$4, U$44.P$7, U$44.P$9, U$44.PWRVIA1, U$44.PWRVIA3, U$44.PWRVIA4, U$44.PWRVIA6, U$45.P$2, U$45.P$4, U$45.P$7, U$45.P$9, U$45.PWRVIA1, U$45.PWRVIA3, U$45.PWRVIA4, U$45.PWRVIA6, U$46.P$2, U$46.P$4, U$46.P$7, U$46.P$9, U$46.PWRVIA1, U$46.PWRVIA3, U$46.PWRVIA4, U$46.PWRVIA6, U$47.P$2, U$47.P$4, U$47.P$7, U$47.P$9, U$47.PWRVIA1, U$47.PWRVIA3, U$47.PWRVIA4, U$47.PWRVIA6, U$48.6
5V9: R17.1, U$49.P$2, U$49.P$4, U$49.P$7, U$49.P$9, U$49.PWRVIA1, U$49.PWRVIA3, U$49.PWRVIA4, U$49.PWRVIA6, U$50.P$2, U$50.P$4, U$50.P$7, U$50.P$9, U$50.PWRVIA1, U$50.PWRVIA3, U$50.PWRVIA4, U$50.PWRVIA6, U$51.P$2, U$51.P$4, U$51.P$7, U$51.P$9, U$51.PWRVIA1, U$51.PWRVIA3, U$51.PWRVIA4, U$51.PWRVIA6, U$52.P$2, U$52.P$4, U$52.P$7, U$52.P$9, U$52.PWRVIA1, U$52.PWRVIA3, U$52.PWRVIA4, U$52.PWRVIA6, U$53.P$2, U$53.P$4, U$53.P$7, U$53.P$9, U$53.PWRVIA1, U$53.PWRVIA3, U$53.PWRVIA4, U$53.PWRVIA6, U$54.6
5V10: R19.1, U$55.P$2, U$55.P$4, U$55.P$7, U$55.P$9, U$55.PWRVIA1, U$55.PWRVIA3, U$55.PWRVIA4, U$55.PWRVIA6, U$56.P$2, U$56.P$4, U$56.P$7, U$56.P$9, U$56.PWRVIA1, U$56.PWRVIA3, U$56.PWRVIA4, U$56.PWRVIA6, U$57.P$2, U$57.P$4, U$57.P$7, U$57.P$9, U$57.PWRVIA1, U$57.PWRVIA3, U$57.PWRVIA4, U$57.PWRVIA6, U$58.P$2, U$58.P$4, U$58.P$7, U$58.P$9, U$58.PWRVIA1, U$58.PWRVIA3, U$58.PWRVIA4, U$58.PWRVIA6, U$59.P$2, U$59.P$4, U$59.P$7, U$59.P$9, U$59.PWRVIA1, U$59.PWRVIA3, U$59.PWRVIA4, U$59.PWRVIA6, U$60.6
5V11: R21.1, U$61.P$2, U$61.P$4, U$61.P$7, U$61.P$9, U$61.PWRVIA1, U$61.PWRVIA3, U$61.PWRVIA4, U$61.PWRVIA6, U$62.P$2, U$62.P$4, U$62.P$7, U$62.P$9, U$62.PWRVIA1, U$62.PWRVIA3, U$62.PWRVIA4, U$62.PWRVIA6, U$63.P$2, U$63.P$4, U$63.P$7, U$63.P$9, U$63.PWRVIA1, U$63.PWRVIA3, U$63.PWRVIA4, U$63.PWRVIA6, U$64.P$2, U$64.P$4, U$64.P$7, U$64.P$9, U$64.PWRVIA1, U$64.PWRVIA3, U$64.PWRVIA4, U$64.PWRVIA6, U$65.P$2, U$65.P$4, U$65.P$7, U$65.P$9, U$65.PWRVIA1, U$65.PWRVIA3, U$65.PWRVIA4, U$65.PWRVIA6, U$66.6
5V12: R23.1, U$67.P$2, U$67.P$4, U$67.P$7, U$67.P$9, U$67.PWRVIA1, U$67.PWRVIA3, U$67.PWRVIA4, U$67.PWRVIA6, U$68.P$2, U$68.P$4, U$68.P$7, U$68.P$9, U$68.PWRVIA1, U$68.PWRVIA3, U$68.PWRVIA4, U$68.PWRVIA6, U$69.P$2, U$69.P$4, U$69.P$7, U$69.P$9, U$69.PWRVIA1, U$69.PWRVIA3, U$69.PWRVIA4, U$69.PWRVIA6, U$70.P$2, U$70.P$4, U$70.P$7, U$70.P$9, U$70.PWRVIA1, U$70.PWRVIA3, U$70.PWRVIA4, U$70.PWRVIA6, U$71.P$2, U$71.P$4, U$71.P$7, U$71.P$9, U$71.PWRVIA1, U$71.PWRVIA3, U$71.PWRVIA4, U$71.PWRVIA6, U$72.6
5V13: R25.1, U$73.P$2, U$73.P$4, U$73.P$7, U$73.P$9, U$73.PWRVIA1, U$73.PWRVIA3, U$73.PWRVIA4, U$73.PWRVIA6, U$74.P$2, U$74.P$4, U$74.P$7, U$74.P$9, U$74.PWRVIA1, U$74.PWRVIA3, U$74.PWRVIA4, U$74.PWRVIA6, U$75.P$2, U$75.P$4, U$75.P$7, U$75.P$9, U$75.PWRVIA1, U$75.PWRVIA3, U$75.PWRVIA4, U$75.PWRVIA6, U$76.P$2, U$76.P$4, U$76.P$7, U$76.P$9, U$76.PWRVIA1, U$76.PWRVIA3, U$76.PWRVIA4, U$76.PWRVIA6, U$77.P$2, U$77.P$4, U$77.P$7, U$77.P$9, U$77.PWRVIA1, U$77.PWRVIA3, U$77.PWRVIA4, U$77.PWRVIA6, U$78.6
5V14: R27.1, U$79.P$2, U$79.P$4, U$79.P$7, U$79.P$9, U$79.PWRVIA1, U$79.PWRVIA3, U$79.PWRVIA4, U$79.PWRVIA6, U$80.P$2, U$80.P$4, U$80.P$7, U$80.P$9, U$80.PWRVIA1, U$80.PWRVIA3, U$80.PWRVIA4, U$80.PWRVIA6, U$81.P$2, U$81.P$4, U$81.P$7, U$81.P$9, U$81.PWRVIA1, U$81.PWRVIA3, U$81.PWRVIA4, U$81.PWRVIA6, U$82.P$2, U$82.P$4, U$82.P$7, U$82.P$9, U$82.PWRVIA1, U$82.PWRVIA3, U$82.PWRVIA4, U$82.PWRVIA6, U$83.P$2, U$83.P$4, U$83.P$7, U$83.P$9, U$83.PWRVIA1, U$83.PWRVIA3, U$83.PWRVIA4, U$83.PWRVIA6, U$84.6
5V15: R29.1, U$85.P$2, U$85.P$4, U$85.P$7, U$85.P$9, U$85.PWRVIA1, U$85.PWRVIA3, U$85.PWRVIA4, U$85.PWRVIA6, U$86.P$2, U$86.P$4, U$86.P$7, U$86.P$9, U$86.PWRVIA1, U$86.PWRVIA3, U$86.PWRVIA4, U$86.PWRVIA6, U$87.P$2, U$87.P$4, U$87.P$7, U$87.P$9, U$87.PWRVIA1, U$87.PWRVIA3, U$87.PWRVIA4, U$87.PWRVIA6, U$88.P$2, U$88.P$4, U$88.P$7, U$88.P$9, U$88.PWRVIA1, U$88.PWRVIA3, U$88.PWRVIA4, U$88.PWRVIA6, U$89.P$2, U$89.P$4, U$89.P$7, U$89.P$9, U$89.PWRVIA1, U$89.PWRVIA3, U$89.PWRVIA4, U$89.PWRVIA6, U$90.6
DATA1: R4.2, U$1.P$3, U$1.P$8, U$1.SIGVIA1, U$1.SIGVIA3, U$8.P$3, U$8.P$8, U$8.SIGVIA1, U$8.SIGVIA3, U$9.P$3, U$9.P$8, U$9.SIGVIA1, U$9.SIGVIA3, U$10.P$3, U$10.P$8, U$10.SIGVIA1, U$10.SIGVIA3, U$11.P$3, U$11.P$8, U$11.SIGVIA1, U$11.SIGVIA3
DATA2: R6.2, U$13.P$3, U$13.P$8, U$13.SIGVIA1, U$13.SIGVIA3, U$14.P$3, U$14.P$8, U$14.SIGVIA1, U$14.SIGVIA3, U$15.P$3, U$15.P$8, U$15.SIGVIA1, U$15.SIGVIA3, U$16.P$3, U$16.P$8, U$16.SIGVIA1, U$16.SIGVIA3, U$17.P$3, U$17.P$8, U$17.SIGVIA1, U$17.SIGVIA3
DATA3: R8.2, U$19.P$3, U$19.P$8, U$19.SIGVIA1, U$19.SIGVIA3, U$20.P$3, U$20.P$8, U$20.SIGVIA1, U$20.SIGVIA3, U$21.P$3, U$21.P$8, U$21.SIGVIA1, U$21.SIGVIA3, U$22.P$3, U$22.P$8, U$22.SIGVIA1, U$22.SIGVIA3, U$23.P$3, U$23.P$8, U$23.SIGVIA1, U$23.SIGVIA3
DATA4: R10.2, U$25.P$3, U$25.P$8, U$25.SIGVIA1, U$25.SIGVIA3, U$26.P$3, U$26.P$8, U$26.SIGVIA1, U$26.SIGVIA3, U$27.P$3, U$27.P$8, U$27.SIGVIA1, U$27.SIGVIA3, U$28.P$3, U$28.P$8, U$28.SIGVIA1, U$28.SIGVIA3, U$29.P$3, U$29.P$8, U$29.SIGVIA1, U$29.SIGVIA3
DATA5: R12.2, U$31.P$3, U$31.P$8, U$31.SIGVIA1, U$31.SIGVIA3, U$32.P$3, U$32.P$8, U$32.SIGVIA1, U$32.SIGVIA3, U$33.P$3, U$33.P$8, U$33.SIGVIA1, U$33.SIGVIA3, U$34.P$3, U$34.P$8, U$34.SIGVIA1, U$34.SIGVIA3, U$35.P$3, U$35.P$8, U$35.SIGVIA1, U$35.SIGVIA3
DATA6: R14.2, U$37.P$3, U$37.P$8, U$37.SIGVIA1, U$37.SIGVIA3, U$38.P$3, U$38.P$8, U$38.SIGVIA1, U$38.SIGVIA3, U$39.P$3, U$39.P$8, U$39.SIGVIA1, U$39.SIGVIA3, U$40.P$3, U$40.P$8, U$40.SIGVIA1, U$40.SIGVIA3, U$41.P$3, U$41.P$8, U$41.SIGVIA1, U$41.SIGVIA3
DATA7: R16.2, U$43.P$3, U$43.P$8, U$43.SIGVIA1, U$43.SIGVIA3, U$44.P$3, U$44.P$8, U$44.SIGVIA1, U$44.SIGVIA3, U$45.P$3, U$45.P$8, U$45.SIGVIA1, U$45.SIGVIA3, U$46.P$3, U$46.P$8, U$46.SIGVIA1, U$46.SIGVIA3, U$47.P$3, U$47.P$8, U$47.SIGVIA1, U$47.SIGVIA3
DATA8: R18.2, U$49.P$3, U$49.P$8, U$49.SIGVIA1, U$49.SIGVIA3, U$50.P$3, U$50.P$8, U$50.SIGVIA1, U$50.SIGVIA3, U$51.P$3, U$51.P$8, U$51.SIGVIA1, U$51.SIGVIA3, U$52.P$3, U$52.P$8, U$52.SIGVIA1, U$52.SIGVIA3, U$53.P$3, U$53.P$8, U$53.SIGVIA1, U$53.SIGVIA3
DATA9: R20.2, U$55.P$3, U$55.P$8, U$55.SIGVIA1, U$55.SIGVIA3, U$56.P$3, U$56.P$8, U$56.SIGVIA1, U$56.SIGVIA3, U$57.P$3, U$57.P$8, U$57.SIGVIA1, U$57.SIGVIA3, U$58.P$3, U$58.P$8, U$58.SIGVIA1, U$58.SIGVIA3, U$59.P$3, U$59.P$8, U$59.SIGVIA1, U$59.SIGVIA3
DATA10: R22.2, U$61.P$3, U$61.P$8, U$61.SIGVIA1, U$61.SIGVIA3, U$62.P$3, U$62.P$8, U$62.SIGVIA1, U$62.SIGVIA3, U$63.P$3, U$63.P$8, U$63.SIGVIA1, U$63.SIGVIA3, U$64.P$3, U$64.P$8, U$64.SIGVIA1, U$64.SIGVIA3, U$65.P$3, U$65.P$8, U$65.SIGVIA1, U$65.SIGVIA3
DATA11: R24.2, U$67.P$3, U$67.P$8, U$67.SIGVIA1, U$67.SIGVIA3, U$68.P$3, U$68.P$8, U$68.SIGVIA1, U$68.SIGVIA3, U$69.P$3, U$69.P$8, U$69.SIGVIA1, U$69.SIGVIA3, U$70.P$3, U$70.P$8, U$70.SIGVIA1, U$70.SIGVIA3, U$71.P$3, U$71.P$8, U$71.SIGVIA1, U$71.SIGVIA3
DATA12: R26.2, U$73.P$3, U$73.P$8, U$73.SIGVIA1, U$73.SIGVIA3, U$74.P$3, U$74.P$8, U$74.SIGVIA1, U$74.SIGVIA3, U$75.P$3, U$75.P$8, U$75.SIGVIA1, U$75.SIGVIA3, U$76.P$3, U$76.P$8, U$76.SIGVIA1, U$76.SIGVIA3, U$77.P$3, U$77.P$8, U$77.SIGVIA1, U$77.SIGVIA3
DATA13: R28.2, U$79.P$3, U$79.P$8, U$79.SIGVIA1, U$79.SIGVIA3, U$80.P$3, U$80.P$8, U$80.SIGVIA1, U$80.SIGVIA3, U$81.P$3, U$81.P$8, U$81.SIGVIA1, U$81.SIGVIA3, U$82.P$3, U$82.P$8, U$82.SIGVIA1, U$82.SIGVIA3, U$83.P$3, U$83.P$8, U$83.SIGVIA1, U$83.SIGVIA3
DATA14: R30.2, U$85.P$3, U$85.P$8, U$85.SIGVIA1, U$85.SIGVIA3, U$86.P$3, U$86.P$8, U$86.SIGVIA1, U$86.SIGVIA3, U$87.P$3, U$87.P$8, U$87.SIGVIA1, U$87.SIGVIA3, U$88.P$3, U$88.P$8, U$88.SIGVIA1, U$88.SIGVIA3, U$89.P$3, U$89.P$8, U$89.SIGVIA1, U$89.SIGVIA3
GND1: C2.2, U$1.GNDVIA1, U$1.GNDVIA3, U$1.GNDVIA4, U$1.GNDVIA6, U$1.P$1, U$1.P$5, U$1.P$6, U$1.P$10, U$8.GNDVIA1, U$8.GNDVIA3, U$8.GNDVIA4, U$8.GNDVIA6, U$8.P$1, U$8.P$5, U$8.P$6, U$8.P$10, U$9.GNDVIA1, U$9.GNDVIA3, U$9.GNDVIA4, U$9.GNDVIA6, U$9.P$1, U$9.P$5, U$9.P$6, U$9.P$10, U$10.GNDVIA1, U$10.GNDVIA3, U$10.GNDVIA4, U$10.GNDVIA6, U$10.P$1, U$10.P$5, U$10.P$6, U$10.P$10, U$11.GNDVIA1, U$11.GNDVIA3, U$11.GNDVIA4, U$11.GNDVIA6, U$11.P$1, U$11.P$5, U$11.P$6, U$11.P$10, U$12.4
GND2: C3.2, U$13.GNDVIA1, U$13.GNDVIA3, U$13.GNDVIA4, U$13.GNDVIA6, U$13.P$1, U$13.P$5, U$13.P$6, U$13.P$10, U$14.GNDVIA1, U$14.GNDVIA3, U$14.GNDVIA4, U$14.GNDVIA6, U$14.P$1, U$14.P$5, U$14.P$6, U$14.P$10, U$15.GNDVIA1, U$15.GNDVIA3, U$15.GNDVIA4, U$15.GNDVIA6, U$15.P$1, U$15.P$5, U$15.P$6, U$15.P$10, U$16.GNDVIA1, U$16.GNDVIA3, U$16.GNDVIA4, U$16.GNDVIA6, U$16.P$1, U$16.P$5, U$16.P$6, U$16.P$10, U$17.GNDVIA1, U$17.GNDVIA3, U$17.GNDVIA4, U$17.GNDVIA6, U$17.P$1, U$17.P$5, U$17.P$6, U$17.P$10, U$18.4
GND3: C4.2, U$19.GNDVIA1, U$19.GNDVIA3, U$19.GNDVIA4, U$19.GNDVIA6, U$19.P$1, U$19.P$5, U$19.P$6, U$19.P$10, U$20.GNDVIA1, U$20.GNDVIA3, U$20.GNDVIA4, U$20.GNDVIA6, U$20.P$1, U$20.P$5, U$20.P$6, U$20.P$10, U$21.GNDVIA1, U$21.GNDVIA3, U$21.GNDVIA4, U$21.GNDVIA6, U$21.P$1, U$21.P$5, U$21.P$6, U$21.P$10, U$22.GNDVIA1, U$22.GNDVIA3, U$22.GNDVIA4, U$22.GNDVIA6, U$22.P$1, U$22.P$5, U$22.P$6, U$22.P$10, U$23.GNDVIA1, U$23.GNDVIA3, U$23.GNDVIA4, U$23.GNDVIA6, U$23.P$1, U$23.P$5, U$23.P$6, U$23.P$10, U$24.4
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

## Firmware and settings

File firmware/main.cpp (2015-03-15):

/*
 * Blinky Controller
 *
* Copyright (c) 2014 Matt Mets
 *
 * based on Fadecandy Firmware, Copyright (c) 2013 Micah Elizabeth Scott
 * 
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
 * THE SOFTWARE IS PROVIDED "AS IS", WITHOUT WARRANTY OF ANY KIND, EXPRESS OR
 * IMPLIED, INCLUDING BUT NOT LIMITED TO THE WARRANTIES OF MERCHANTABILITY, FITNESS
 * FOR A PARTICULAR PURPOSE AND NONINFRINGEMENT. IN NO EVENT SHALL THE AUTHORS OR
 * COPYRIGHT HOLDERS BE LIABLE FOR ANY CLAIM, DAMAGES OR OTHER LIABILITY, WHETHER
 * IN AN ACTION OF CONTRACT, TORT OR OTHERWISE, ARISING FROM, OUT OF OR IN
 * CONNECTION WITH THE SOFTWARE OR THE USE OR OTHER DEALINGS IN THE SOFTWARE.
 */

#include <math.h>
#include <algorithm>
#include <stdlib.h>
#include <stdio.h>
#include "fc_usb.h"
#include "arm_math.h"
#include "HardwareSerial.h"
#include "usb_serial.h"

#include "blinkytile.h"
#include "animation.h"
#include "jedecflash.h"
#include "nofatstorage.h"
#include "dmx.h"
#include "addressprogrammer.h"
#include "patterns.h"
#include "serialloop.h"
#include "buttons.h"

// USB data buffers
static fcBuffers buffers;
fcLinearLUT fcBuffers::lutCurrent;

// External flash chip
FlashSPI flash;

// Flash storage class, works on top of the base flash chip
NoFatStorage flashStorage;

// Animations class
Animations animations;

// Button inputs
Buttons userButtons;

// Reserved RAM area for signalling entry to bootloader
extern uint32_t boot_token;

// Token to signal that the animation loop should be restarted
volatile bool reloadAnimations;

static void dfu_reboot()
{
    // Reboot to the Fadecandy Bootloader
    boot_token = 0x74624346;

    // Short delay to allow the host to receive the response to DFU_DETACH.
    uint32_t deadline = millis() + 10;
    while (millis() < deadline) {
        watchdog_refresh();
    }

    // Detach from USB, and use the watchdog to time out a 10ms USB disconnect.
    __disable_irq();
    USB0_CONTROL = 0;
    while (1);
}

extern "C" int usb_fc_rx_handler()
{
    // USB packet interrupt handler. Invoked by the ISR dispatch code in usb_dev.c
    return buffers.handleUSB();
}


void setupWatchdog() {
    // Change the watchdog timeout because the SPI access is too slow.
    const uint32_t watchdog_timeout = F_BUS / 2;  // 500ms

    WDOG_UNLOCK = WDOG_UNLOCK_SEQ1;
    WDOG_UNLOCK = WDOG_UNLOCK_SEQ2;
    asm volatile ("nop");
    asm volatile ("nop");
    WDOG_STCTRLH = WDOG_STCTRLH_ALLOWUPDATE | WDOG_STCTRLH_WDOGEN |
        WDOG_STCTRLH_WAITEN | WDOG_STCTRLH_STOPEN | WDOG_STCTRLH_CLKSRC;
    WDOG_PRESC = 0;
    WDOG_TOVALH = (watchdog_timeout >> 16) & 0xFFFF;
    WDOG_TOVALL = (watchdog_timeout)       & 0xFFFF;
}

extern "C" int main()
{
    setupWatchdog();

    initBoard();

    userButtons.setup();

    dmxSetup();

    enableOutputPower();

    serialReset();

    flash.begin(FlashClass::autoDetect);

    reloadAnimations = true;

    // Application main loop
    while (usb_dfu_state == DFU_appIDLE) {
        watchdog_refresh();
       
        // TODO: put this in an ISR? Make the buttons do pin change interrupts?
        userButtons.buttonTask();

        #define BRIGHTNESS_COUNT 5
        static int brightnessLevels[BRIGHTNESS_COUNT] = {30,60,100,150,255};
        static int brightnessStep = BRIGHTNESS_COUNT-1;

        static bool streaming_mode;

        static int animation;          // Flash animation to show
        static int frame;              // current frame to display
        static uint32_t nextTime;           // Time to display next frame

        dmxSetBrightness(brightnessLevels[brightnessStep]);

        if(reloadAnimations) {
            reloadAnimations = false;
            flashStorage.begin(flash);
            animations.begin(flashStorage);

            streaming_mode = false;
            animation = 0;
            frame = 0;
            nextTime = 0;
        }

        if(!streaming_mode) {
            // If the flash wasn't initialized, show a default flashing pattern
            if(animations.getCount() == 0) {
                count_up_loop();
                dmxShow();
            }
            else {

                // Flash-based
                if(millis() > nextTime) {
                    animations.getAnimation(animation)->getFrame(frame, dmxGetPixels());
                    frame++;
                    if(frame >= animations.getAnimation(animation)->frameCount) {
                        frame = 0;
                    }
    
                    nextTime += animations.getAnimation(animation)->speed;
    
                    // If we've gotten too far ahead of ourselves, reset the counter
                    if(millis() > nextTime) {
                        nextTime = millis() + animations.getAnimation(animation)->speed;
                    }
    
                    dmxShow();
                }
            }
        }

        // Handle fadecandy status messages
        if(buffers.finalizeFrame()) {
	    streaming_mode = true;

            if(!dmxWaiting()) {
                for(int i = 0; i <  LED_COUNT; i++) {
                    dmxSetPixel(i, *(buffers.fbNext->pixel(i)+2),
                                   *(buffers.fbNext->pixel(i)+1),
                                   *(buffers.fbNext->pixel(i)));
                }
                dmxShow();
            }
        }

        // Check for serial data
        if(usb_serial_available() > 0) {
            streaming_mode = true;
            serialLoop();
        }

        if(userButtons.isPressed()) {
            uint8_t button = userButtons.getPressed();
    
            if(button == BUTTON_A) {
                animation = (animation + 1)%animations.getCount();
                frame = 0;
            }
            else if(button == BUTTON_B) {
                brightnessStep = (brightnessStep + 1) % BRIGHTNESS_COUNT;
                dmxSetBrightness(brightnessLevels[brightnessStep]);
            }
        }

    }

    // Reboot into DFU bootloader
    dfu_reboot();
}

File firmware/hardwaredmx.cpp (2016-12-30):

#include "WProgram.h"
#include "pins_arduino.h"
#include "dmx.h"
#include "blinkytile.h"
#include "brightness_table.h"

//#define FAST_DMX

#ifdef FAST_DMX

#define BAUD_RATE                500000

#define FRAME_SPACING            4000         // uS between frames
#define BREAK_LENGTH             88
#define MAB_LENGTH               8

#else

#define BAUD_RATE                250000

#define FRAME_SPACING            4000         // uS between frames
#define BREAK_LENGTH             100
#define MAB_LENGTH               8

#endif

#define BAUD2DIV(baud)  (((F_CPU * 2) + ((baud) >> 1)) / (baud))


#define INPUT_BYTES              LED_COUNT*BYTES_PER_PIXEL
#define OUTPUT_BYTES             1 + LED_COUNT*BYTES_PER_PIXEL

uint8_t drawBuffer[INPUT_BYTES];        // Buffer for the user to draw into
uint8_t dmaBuffer[2][OUTPUT_BYTES];     // Double-buffered output for the DMA engine
uint8_t* frontBuffer;
uint8_t* backBuffer;
bool swapBuffers;

uint8_t brightness;

bool isEnabled = false;         // True if the engine is enabled
bool isTransmitting = false;    // True if currently transmitting a DMX frame

// TCD0 writes DMX channel data to the UART 
void setupDMA(uint8_t* source, int minorLoopSize, int majorLoops) {
    // Set up the DMA peripheral
    SIM_SCGC6 |= SIM_SCGC6_DMAMUX;  // Enable clocks
    SIM_SCGC7 |= SIM_SCGC7_DMA;
 
    DMA_TCD0_SADDR = source;                                        // Address to read from
    DMA_TCD0_SOFF = 1;                                              // Bytes to increment source register between writes 
    DMA_TCD0_SLAST = 0;                                             // Bytes to add after a major iteration count (N/A)
 
    DMA_TCD0_DADDR = &UART1_D;                                      // Address to write to
    DMA_TCD0_DOFF = 0;                                              // Bytes to increment destination register between write
    DMA_TCD0_DLASTSGA = 0;                                          // Address of next TCD (N/A)
 
    DMA_TCD0_ATTR = DMA_TCD_ATTR_SSIZE(0) | DMA_TCD_ATTR_DSIZE(0);  // 8-bit input and output
    DMA_TCD0_NBYTES_MLNO = minorLoopSize;                           // Number of bytes to transfer in the minor loop
    DMA_TCD0_CITER_ELINKNO = majorLoops;                            // Number of major loops to complete
    DMA_TCD0_BITER_ELINKNO = majorLoops;                            // Reset value for CITER (must be equal to CITER)
 
    // Timer DMA channel:
    // Configure DMAMUX to trigger DMA0 from FTM1_CH0
    DMAMUX0_CHCFG0 = DMAMUX_DISABLE;
    DMAMUX0_CHCFG0 = DMAMUX_SOURCE_UART1_TX | DMAMUX_ENABLE;
    DMA_TCD0_CSR = DMA_TCD_CSR_DREQ | DMA_TCD_CSR_START;       // Start the transaction

    // Enable interrupt on major completion for DMX data
    DMA_TCD0_CSR = DMA_TCD_CSR_INTMAJOR;  // Enable interrupt on major complete
    NVIC_ENABLE_IRQ(IRQ_DMA_CH0);         // Enable interrupt request

    isEnabled = true;
}

void scheduleDMA(uint8_t* source, int length) {
    DMA_TCD0_SADDR = source;                                    // Address to read from
    DMA_TCD0_NBYTES_MLNO = 1;                                   // Number of bytes to transfer in the minor loop
    DMA_TCD0_CITER_ELINKNO = length;                            // Number of major loops to complete
    DMA_TCD0_BITER_ELINKNO = length;                            // Reset value for CITER (must be equal to CITER)
    DMA_SERQ = DMA_SERQ_SERQ(0);

    PORTC_PCR4 = PORT_PCR_DSE | PORT_PCR_SRE | PORT_PCR_MUX(3);	// Configure TX Pin for UART
}

void setupUart() {
    uint32_t divisor = BAUD2DIV(BAUD_RATE);

    SIM_SCGC4 |= SIM_SCGC4_UART1;	// turn on clock
    PORTC_PCR4 = PORT_PCR_DSE | PORT_PCR_SRE | PORT_PCR_MUX(3);	// Configure TX Pin

    UART1_C2 = 0;	// disable transmitter

    UART1_BDH = (divisor >> 13) & 0x1F;  // baud rate
    UART1_BDL = (divisor >> 5) & 0xFF;
    UART1_C4 = divisor & 0x1F;

    UART1_C1 = UART_C1_M;
    UART1_S2 = 0;
    UART1_C3 = (uint8_t)(0x40);  // 9th data bit as faux stop bit
    UART1_C5 = (uint8_t)(0x80); // TDMAS

    UART1_PFIFO = UART_PFIFO_TXFE;
    UART1_TWFIFO = 0;	// Set the watermark to 0 byte

    //UART1_C2 = UART_C2_TIE | UART_C2_TE;
    UART1_C2 = UART_C2_TE;
}

bool dmxIsTransmitting() {
    return isTransmitting;
}

bool dmxIsEnabled() {
    return isEnabled;
}

// Stop the DMX output engine
void dmxStop() {
    isEnabled = false;
}
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

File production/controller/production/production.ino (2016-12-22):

/*
 * Fadecandy testjig firmware for production.
 * This loads an initial bootloader/firmware image on the device, and runs electrical tests.
 *
 * Communicates with the PC for debug purposes using USB-Serial.
 * Final OK / Error status shows up on WS2811 LEDs attached to the DUT.
 */

#include "arm_kinetis_debug.h"
#include "arm_kinetis_reg.h"
#include "fc_remote.h"
#include "electrical_test.h"
#include "testjig.h"

//ARMKinetisDebug target(swclkPin, swdioPin);
ARMKinetisDebug target(swclkPin, swdioPin, ARMDebug::LOG_NORMAL);
//ARMKinetisDebug target(swclkPin, swdioPin, ARMDebug::LOG_TRACE_POWER);
FcRemote remote(target);
ElectricalTest etest(target);

void setup()
{
    pinMode(ledPin, OUTPUT);
    pinMode(ledPassPin, OUTPUT);
    pinMode(ledFailPin, OUTPUT);
    pinMode(buttonPin, INPUT_PULLUP);
    analogReference(INTERNAL);
    Serial.begin(115200);
}

void waitForButton()
{
    // Wait for button press, with debounce

    Serial.println("");
    Serial.println("----------------------------------------------");
    Serial.println(" Blinkinlabs Test Jig : Press button to start");
    Serial.println("----------------------------------------------");
    Serial.println("");

    while (digitalRead(buttonPin) == LOW);
    delay(20);
    while (digitalRead(buttonPin) == HIGH) {
        // While we're waiting, blink the LED to indicate we're alive
        digitalWrite(ledPin, (millis() % 1000) < 150);
    }
    digitalWrite(ledPin, HIGH);
}

void success()
{
    Serial.println("");
    Serial.println("#### Tests Passed! ####");
    Serial.println("");

//    // Green and blue throbbing means success!
//    while (1) {
//        float x = sin(millis() * 0.008);
//        if (!remote.setPixel(0, 0, 0xc + 0x10 * x, 0)) return;
//        if (!remote.setPixel(1, 0, 0, 0xc - 0x10 * x)) return;
//    }
}

#define TEST_UNTESTED 0
#define TEST_FAIL 1
#define TEST_PASS 2
int testState = TEST_UNTESTED;


void loop()
{
    // Keep target power supply off when we're not using it
    etest.powerOff();
    
    // Set the status LEDs
    if(testState == TEST_FAIL) {
      digitalWrite(ledPassPin, LOW);
      digitalWrite(ledFailPin, HIGH);
    }
    else if(testState == TEST_PASS) {
      digitalWrite(ledPassPin, HIGH);
      digitalWrite(ledFailPin, LOW);
    }
    else {
      digitalWrite(ledPassPin, HIGH);
      digitalWrite(ledFailPin, HIGH);
    }      
      
    // Button press starts the test
    waitForButton();
    
    testState = TEST_FAIL;
    digitalWrite(ledPassPin, HIGH);
    digitalWrite(ledFailPin, HIGH);

    // Turn on the target power supply
    if (!etest.powerOn())
        return;
        
    // Start debugging the target
    if (!target.begin())
        return;
    if (!target.startup())
        return;

    // Run an electrical test, to verify that the target board is okay
    if (!etest.runAll())
        return;

    // Test for the presence of the flash chip
    if (!remote.testExternalFlash(false))
        return;

    // Program firmware, blinking both LEDs in unison for status.
    if (!remote.installFirmware())
        return;
        
        
    // Test that the user buttons work
    if (!remote.testUserButtons())
        return;

    // Boot the target
    if (!remote.boot())
        return;
    
//    // Disable interpolation, since we only update fbNext
//    if (!remote.setFlags(CFLAG_NO_INTERPOLATION))
//        return;
//
//    // Set a default color lookup table
//    if (!remote.initLUT())
//        return;
//
//    // Pixel pattern to display while running the frame rate test (white / green)
//    if (!remote.setPixel(0, 16, 16, 16)) return;
//    if (!remote.setPixel(1, 0, 24, 0)) return;
//
//    // Check the frame rate; make sure the firmware is going fast enough
//    if (!remote.testFrameRate())
//        return;

    testState = TEST_PASS;
    success();
}

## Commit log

2014-06-20 Proof of concept version; seems to work!
    [background.SLDPRT, cable.SLDPRT, design.SLDASM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]
2014-06-20 Move all components to top side
    [dodocohedreled.brd, dodocohedreled.sch]
2014-06-20 Add stop mask to test points.
    [dodocohedreled.brd]
2014-06-22 Add silk, place order for RevB version
    [dodocohedreled.brd]
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2014-08-19 Switch to WS2822S module, bump to RevD.
    [dodocohedreled.brd, dodocohedreled.sch]
2014-08-20 Add panel design prototype
    [dodocohedreled_panel.brd]
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2014-09-01 Rev E of pcb, control pcb
    [BlinkyTile_controller.brd, BlinkyTile_controller.sch, BlinkyTile_panel2.brd]
2014-09-01 Put address line on edge, tighten R and C positions
    [BlinkyTile.brd, BlinkyTile_panel2.brd]
2014-09-02 Add RevF panel design, as submitted
    [BlinkyTile_panel.brd]
2014-09-02 Bump to RevF: shaped solder masks for different signals
    [BlinkyTile.brd, BlinkyTile.sch]
2014-09-04 Add Test Jig PCB from Sam, first pass at firmware
    [Blinkytile tester.brd, Blinkytile tester.sch]
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2014-09-09 Add tile test/address programming jig
    [programmer base.SLDPRT, programmer base.STL]
2014-10-06 Add plastic pyramid design
    [pyramid_nostep.SLDPRT, pyramid_nostep.STL]
2014-10-11 Add Controller from Sam
    [BlinkyTile Controller.brd, BlinkyTile Controller.sch]
2014-10-11 Rev 5 panel design by Sam
    [BlinkyTile_panel.brd]
2014-10-11 Rev 6 panel design (as submitted for prototype PCB)
    [BlinkyTile_panel.brd]
2014-10-11 PCB design: add dimensions
    [BlinkyTile.brd]
2014-10-14 RevB of tester board: add 5v buffers
    [Blinkytile tester.brd, Blinkytile tester.sch]
2014-10-14 added injection moldable version of pyramid topper
    [pyramid_nostep-revB.SLDPRT]
2014-10-15 Update controller board design for RevA
    [BlinkyTile Controller.brd, BlinkyTile Controller.sch]
2014-10-20 Switch to smaller processor, change FLASH_CS to hardware CS pin
    [BlinkyTile Controller.brd, BlinkyTile Controller.sch]
2014-10-21 Rev J panel: Add larger spaces in centers between tiles, tighten up edges.
    [BlinkyTile_panel.brd]
2014-10-22 Update to RevB controller from Sam
    [BlinkyTile Controller.brd, BlinkyTile Controller.sch]
2014-10-23 Add extra vias for input power to the 5v mosfet
    [BlinkyTile Controller.brd, BlinkyTile Controller.sch]
2014-10-23 Remove outdated tile controller
    [BlinkyTile_controller.brd, BlinkyTile_controller.sch]
2014-10-23 Add higher-speed DMX test. Doesn't conform to a standard.
    [main.cpp]
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2014-10-26 Bugfix: use correct frame length when reading animations
    [main.cpp]
2014-10-26 PCB updates: Drop pullup resistors, change connector
    [BlinkyTile Controller.brd, BlinkyTile Controller.sch]
2014-10-27 Updated controller and panel designs
    [BlinkyTile Controller.brd, BlinkyTile Controller.sch, BlinkyTile_panel.brd]
2014-10-27 Updated controller board, by Sam
    [BlinkyTile Controller.brd, BlinkyTile Controller.sch]
2014-10-28 Update controller: move R5 to 3.3v, reduce panel size, move more routing to top layer
    [BlinkyTile Controller.brd, BlinkyTile Controller.sch]
2014-10-28 Add stopmask under processor ground, fix silkscreen
    [BlinkyTile Controller.brd, BlinkyTile Controller.sch]
2014-11-02 Controller: Change .1" header footprint to Sparkfun version, make text larger
    [BlinkyTile Controller.brd, BlinkyTile Controller.sch]
2014-11-03 Prepare for a 64k system; fix timing bug in display code
    [main.cpp]
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2014-11-03 Update panel
    - fixed connector board error
    - added fiducial marker at corner
    - removed mounting holes at side
    - removed 2 connector boards on panel
    - added remark for blinkyTile signal
    [BlinkyTile_panel.brd]
2014-11-03 Fix error on text
    [BlinkyTile_panel.brd]
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2014-11-04 Controller: move end of 3.3v trace to improve grounding, replace switch, resize 5v line
    [BlinkyTile Controller.brd, BlinkyTile Controller.sch]
2014-11-04 Change 4p output connector, push switches in a bit
    [BlinkyTile Controller.brd, BlinkyTile Controller.sch]
2014-11-04 Update flash type, add .254mm isolation on top&bottom copper, general cleanup
    [BlinkyTile Controller.brd, BlinkyTile Controller.sch]
2014-11-04 beef up power line widths
    [BlinkyTile Controller.brd]
2014-11-05 Add ferrite beads, move the fuse to the ouput.
    [BlinkyTile Controller.brd, BlinkyTile Controller.sch]
2014-11-06 Tidy schematic and add values to ferrites, crystal
    [BlinkyTile Controller.brd, BlinkyTile Controller.sch]
2014-11-06 Enlarge via sizes to .3mm
    [BlinkyTile Controller.brd, BlinkyTile Controller.sch]
2014-11-07 Controller: Switch back to 208 package for flash chip
    [BlinkyTile Controller.brd, BlinkyTile Controller.sch]
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2014-11-11 Add protection diode, JST battery connector, tweak positions for manufacturability, redo silk
    [BlinkyTile Controller.brd, BlinkyTile Controller.sch]
2014-11-11 Rev M panel from Sam
    [BlinkyTile_panel.brd]
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2014-11-18 Move tile test jig location
    [Blinkytile tester.brd, Blinkytile tester.sch]
2014-11-18 Clean up schematic layout
    [BlinkyTile Controller.brd, BlinkyTile Controller.sch]
2014-11-20 Add sector descriptor format
    [Flash sector format.xls]
2014-11-21 Getting the tile test rig working: small circuit design issues.
    [Blinkytile tester.sch]
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2014-11-23 Controller boar design, as released.
    [BlinkyTile Controller.brd, BlinkyTile Controller.sch]
2014-11-23 Controller pcb, as fixed
    [BlinkyTile Controller.brd, BlinkyTile Controller.sch]
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2014-11-23 Add test jig design for controller
    [controller testjig.brd, controller testjig.sch]
2014-11-25 Add notes for reworking controller testjig pcb
    [controller testjig.sch]
2014-11-25 Update production test to minimal working function
    [controller testjig.brd, controller testjig.sch]
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2014-11-27 Add button test, board pin short tests, output tests
    [electrical_test.cpp, fc_remote.cpp, production.ino]
2014-11-29 Small bugfix to test rig firmware
    [TestRig.ino]
2014-11-29 Firmware bugfix: ping watchdog while writing to flash, to prevent tripping it when waiting for large flash to erase
    [main.cpp, winbondflash.cpp]
2014-12-01 Fix string names of usb interfaces, remove teensyduino reset sequence, DFU reset broken?
2014-12-04 BlinkyTile TestRig for production
    - Bugs fixed
    - automatic program address (1-14) then verify address and test color
    - added erase command
    - added test color command
    [TestRig.ino]
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2014-12-08 Bugfix: toggle flash write protect between writes/deletes
    [Flash sector format.xls]
2014-12-10 Get things compiled again, serial working but fc not working.
    [main.cpp]
2014-12-11 Attempted (and failed) speedups to the production test
    [production.ino]
2014-12-11 Fix up the DMX timing a bit, address programming.
    [addressprogrammer.cpp]
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2014-12-12 Snapshot of broken upload code
    [blinkytape.py, commandTests.py]
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2015-03-04 Buggy support for fadecandy (high framerates lock up USB)
    [main.cpp]
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2015-03-14 Bugfix: restore brightness button with hardware DMX output
    [hardwaredmx.cpp]
2015-03-15 Throw in an 8-bit brightness correction table
    [hardwaredmx.cpp, main.cpp]
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2015-04-02 Add slim controller design from Sam
    [BlinkyTape Controller.brd, BlinkyTape Controller.sch]
2015-04-02 Rework board to be 29mm, use 0603 package for main cap, add bottom side pad for VUSB, improve +5V routing
    [BlinkyTape Controller.brd, BlinkyTape Controller.sch]
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2015-11-17 Add art to single-tile pentagon
    [BlinkyTile.brd]
2016-02-28 Control Board: make USB pads longer, update silkscreen (RevE)
    [BlinkyTile Controller.brd, BlinkyTile Controller.sch]
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2016-10-25 Fix file case problem
    [jedecflash.cpp]
2016-12-22 Move test files into new directories
    [Blinkytile tester.brd, Blinkytile tester.sch, controller testjig.brd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]
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2016-12-22 Update note about board
    [BlinkyTile Controller.brd, BlinkyTile Controller.sch]
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2016-12-22 Add debugging info for voltage tests, fix tolerances
    [electrical_test.cpp, fc_remote.cpp, production.ino]
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

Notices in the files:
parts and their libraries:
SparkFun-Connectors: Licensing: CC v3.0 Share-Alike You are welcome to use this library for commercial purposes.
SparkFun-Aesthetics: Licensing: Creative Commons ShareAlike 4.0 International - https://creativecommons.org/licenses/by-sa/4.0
